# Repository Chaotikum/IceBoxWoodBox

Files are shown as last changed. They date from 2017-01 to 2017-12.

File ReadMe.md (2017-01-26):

# IceBoxWoodBox

Eine kleine Holzbox für die Icebox im nbsp;
die ersten Skizzen sind da, die Maße noch nicht endgültig alle geprüft, aber
ein erster Papier-Prototyp funktionierte ganz gut, von der Größe der
kleinen inneren Box abgesehen.
Im Nachtragen aller Maße (siehe erste Skizze, die bereits fertig ist), werden
die aufgefallenen Mängel mit behoben.

Außerdem müsste danach jemand lasern.

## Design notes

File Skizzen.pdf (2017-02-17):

# Die IceBoxWoodBox

An felgender erster Grafik sind alle Werte verzeichnet, die sich per Variable ändern lassen: Tiefe (oben) Höhe (vorne), Displayhöhe, (in dieser Grafik nicht enthalten: Displaybreite), Holzdicke, sowie Höhe und Tiefe der inneren Box.

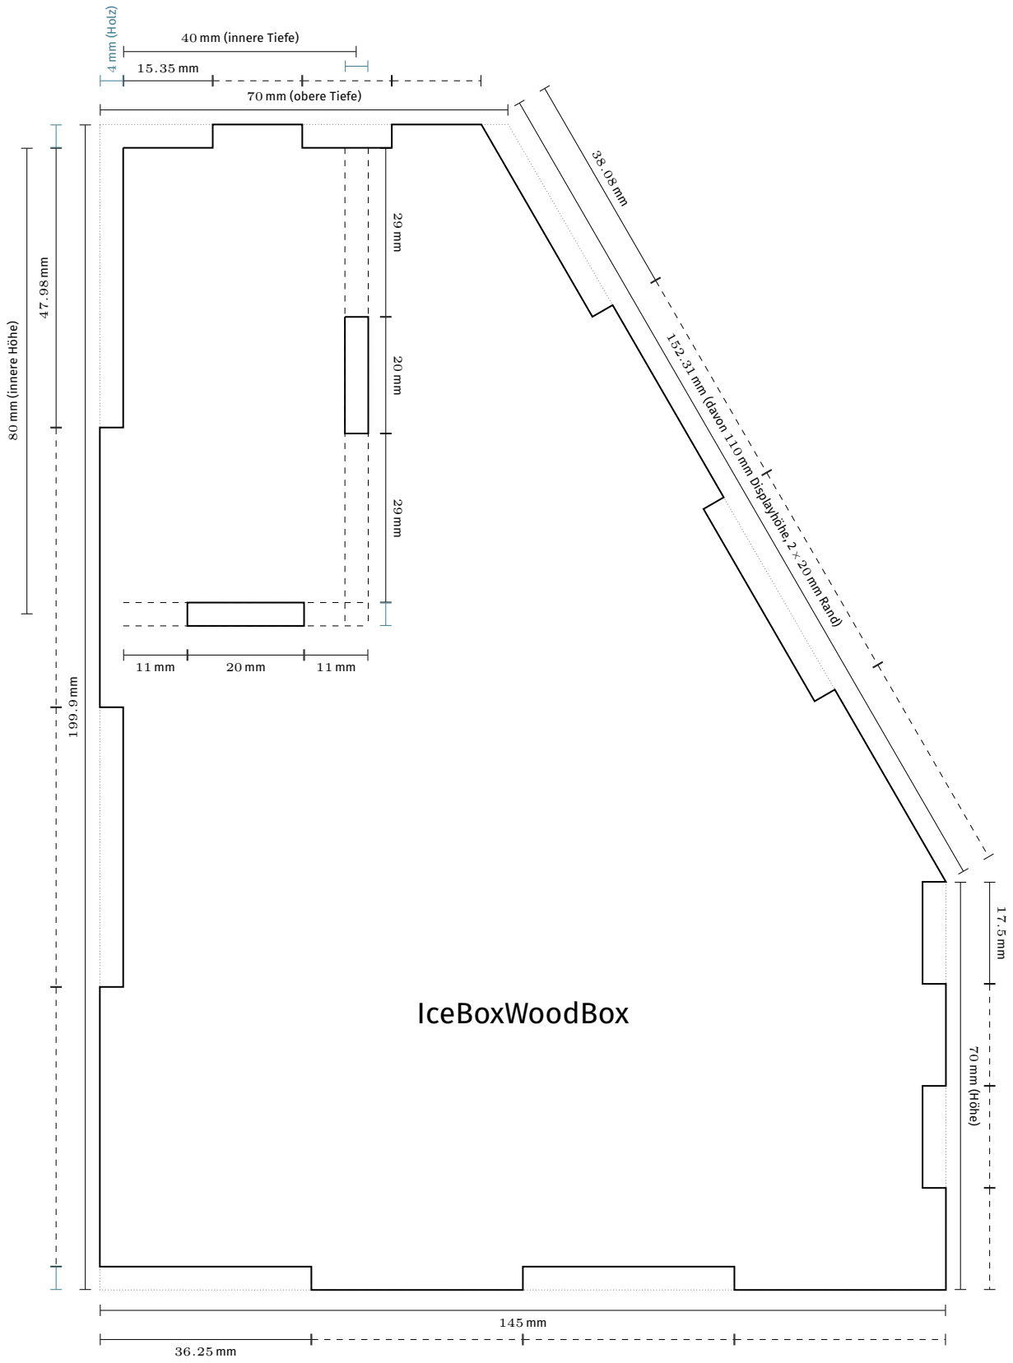
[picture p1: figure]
IceBoxWoodBox; 70 mm (obere Tiefe); mm (Holz); 40 mm (innere Tiefe); 152.31 mm (davon; 110 mm Displayhöhe, 2 × 20 mm Rand); 70 mm (Höhe); 80 mm (innere Höhe)

1 – (linke) Seitenansicht, die rechte Seite ist natürlich identisch, bzw. lediglich gespiegelt.

# Spenden- & Getränkekasse

Hinten
Vorne

69.38 mm

15.35 mm

40 mm (innere Tiefe)

7.5 mm (Geldschlitztiefe)

210 mm (davon 170 mm Display-Breite und 2×20 mm Display-Rand)

40.4 mm

40 mm (Geldschlitzt-Breite)

2 – Oberseite (links hinten, rechts vorne)

Oben

51.98 mm | 47.98 mm

80 mm (innere Höhe)

210 mm (davon 170 mm Display-Breite und 2×20 mm Display-Rand)

44.4 mm 40.4 mm 40.4 mm 40.4 mm 44.4 mm

42.5 mm 20 mm 85 mm 20 mm 42.5 mm

3 – Rückseite

Back

Front

210 mm (davon 170 mm Display-Breite und 2×20 mm Display-Rand)

44.4 mm 40.4 mm 40.4 mm 40.4 mm 44.4 mm

145 mm

36.25 mm | 35.85 mm
4 – Unterseite

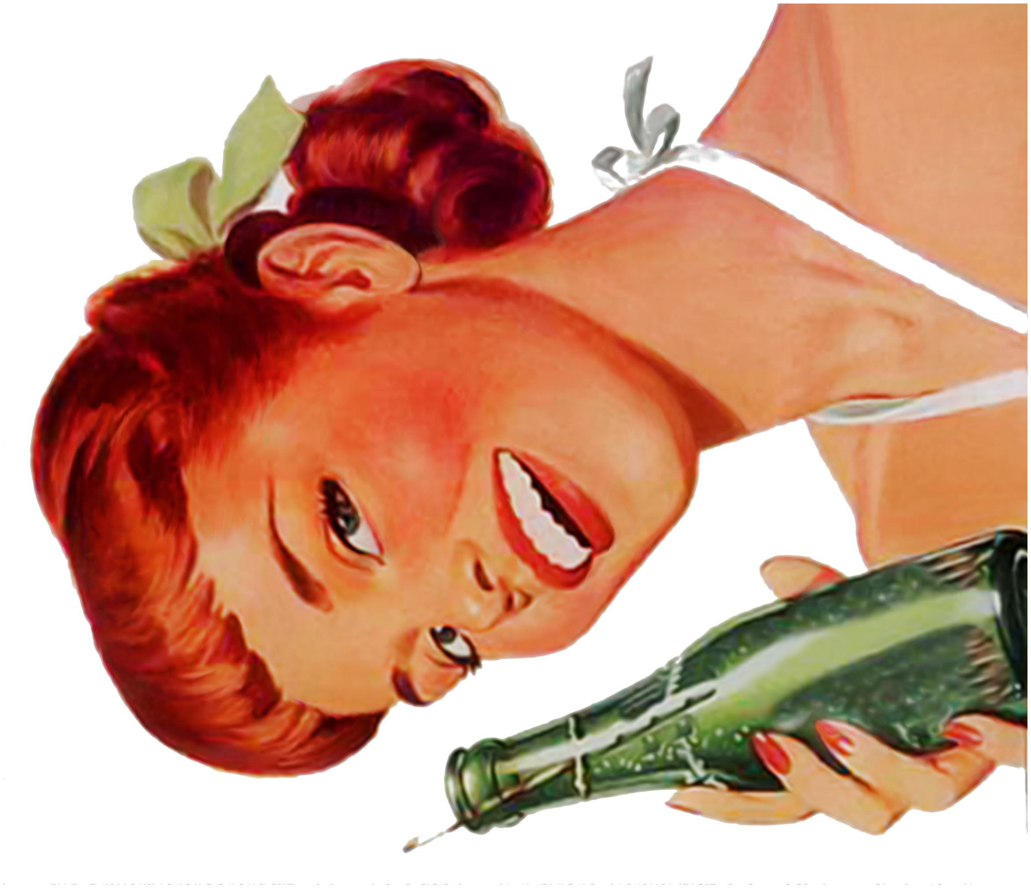
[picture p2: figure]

# icebox.nobreakspace.org

Klick dir ’ne Mate.

oben, ohne Finger, Kante zur Schräge

Unten

210 mm (davon 170 mm Display-Breite und 2×20 mm Display-Rand)

44.4 mm 40.4 mm 40.4 mm 40.4 mm 44.4 mm

70 mm (Höhe)

17.5 mm
5 – Frontblende unten

oben

vorne

210 mm (davon 170 mm Display-Breite und 2×20 mm Display-Rand)

44.4 mm 40.4 mm 40.4 mm 40.4 mm 44.4 mm

147.69 mm (vgl. Seitenansicht, gekürztes unteres Ende, damit die Schräge nicht übersteht)

38.08 mm | 33.46 mm
6 – Displayplatte

top

bottom
202 mm

38.5 mm 20 mm 85 mm 20 mm 38.5 mm

40.4 mm

80 mm (innere Höhe)

29 mm | 20 mm | 29 mm
7 – innere Box – Rückseite

back

front
202 mm

38.5 mm 20 mm 85 mm 20 mm 38.5 mm

40.4 mm

40 mm (innere Tiefe)

9 mm | 20 mm | 9 mm
8 – Boxbox-Unterseite

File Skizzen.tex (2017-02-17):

% !TEX TS-program = xelatex
% !TEX TS-options = --shell-escape

%
% A unified file to generate the sketches (PDF/Vectorgraphics) of the
%   Stackenblocken Pixel construction
%
% @kellertuer, 2017-01-01
\documentclass[a4paper,DIV=19]{scrartcl}
\usepackage[no-math]{fontspec}
\usepackage{xunicode,xltxtra}
\usepackage{tikz}
\usepackage{unicode-math,graphicx}
\usepackage[ngerman]{babel}
\usetikzlibrary{calc,external}
\tikzexternalize
\pagestyle{empty}
% Font
\defaultfontfeatures{Mapping=tex-text}
\setromanfont[Ligatures={Common}]{Fira Sans}
%
% Styles
\tikzset{base/.style={gray,densely dotted,thin}}
\tikzset{main/.style={thick}}
\tikzset{minor/.style={dashed}}
\tikzset{holes/.style={thick,fill=yellow!20}}
\tikzset{magnets/.style={thick,fill=cyan!20}}
\tikzset{measure/.style={thin,|-|}}
\tikzset{measureW/.style={thin,|-|,cyan!50!black}}
\tikzset{measure2/.style={thin,|-|,dashed}}
\tikzset{emph/.style={fill=cyan!10!white,cyan!60!white}}
\tikzset{neo/.style={fill=cyan!20!white,cyan!60!white}}
\tikzset{every node/.style={font=\tiny}}
%
% Details anzeigen oder nur Schnittlinien?
\newif\ifshowDetails
\showDetailstrue
%\showDetailsfalse
\ifshowDetails
  \tikzexternalize[prefix=SkizzeKompl-]
\else
  \tikzexternalize[prefix=Skizze-]
\fi
%
%
% Größenangaben
%
% if unsure leave them as they're because that's the production standard for now
\newcommand\DisplayWidth{17} %Displaybreite (brutto)
\newcommand\DisplayHeight{11} %DisplayHöhe
\newcommand\DisplayBorder{2} %(Holz-)Rand um das Displayplexi frontplare Thickness
\newcommand\Depth{7} %Tiefe hinter dem Display bzw unter dem Display
\newcommand\Height{7} %Höhe unter dem Display bzw unter dem Display
\newcommand\Boxboxdepth{4} % Tiefe der Gelbdbox
\newcommand\Boxboxheight{8} % Höhe der inneren Box
\newcommand\wood{0.4} % Das ist mein Holz

\newcommand\slotWidth{4}
\newcommand\slotHeight{0.75}

%Helper Values -- Bitte nicht bearbeiten
\newcommand\side{(\DisplayHeight+2*\DisplayBorder)}
\newcommand\sideHeight{\side*sin(60)}
\newcommand\sideWidth{\side*cos(60)}
\newcommand\topF{(\DisplayWidth+2*\DisplayBorder-2*\wood)}
\newcommand\measureOffSet{0.5}
\begin{document}
  \begin{center}
    \Huge Die IceBoxWoodBox
  \end{center}
  An felgender erster Grafik sind alle Werte verzeichnet, die sich per Variable ändern lassen:
  Tiefe (oben) Höhe (vorne), Displayhöhe, (in dieser Grafik nicht enthalten: Displaybreite),
  Holzdicke, sowie Höhe und Tiefe der inneren Box.
  \newpage\enlargethispage{3\baselineskip}
  \begin{center}
    \tikzsetnextfilename{Links}
    \tikzexternaldisable
    \begin{tikzpicture}
      % Elementgrenzen und andere Holzteile im Anschnitt
      \ifshowDetails
        \draw[base] (0,0) -- ++(\Depth,0)
            -- ++({\sideWidth},{-\sideHeight}) -- ++(0,-\Height) node (BottomRight) {}
            -- ++ (-\Depth,0) -- ++ ({-\sideWidth},0) node (Bottom Left) {} -- cycle;
      \fi
      % Umriss
      \draw[main] (\wood,-\wood) -- ++ ({((\Depth-\wood-\wood/sin(60))/4},0) -- ++ (0,\wood)
          -- ++ ({(\Depth-\wood-\wood/sin(60))/4},0) -- ++ (0,-\wood) 
          -- ++ ({(\Depth-\wood-\wood/sin(60))/4},0)
          -- ++ (0,\wood) -- ++ ({(\Depth-\wood-\wood/sin(60))/4},0) node (TR) {}
        -- ++ (300:{(\side+\wood/tan(60))/4}) -- ++ (30:\wood)
        -- ++ (300:{(\side+\wood/tan(60))/4}) -- ++ (210:\wood)
        -- ++ (300:{(\side+\wood/tan(60))/4}) -- ++ (30:\wood)
        -- ++ (300:{(\side+\wood/tan(60))/4}) node (BR) {} -- ++ (180:\wood) 
        -- ++ (270:{\Height/4}) -- ++ (0:\wood)
        -- ++ (270:{\Height/4}) -- ++ (180:\wood)
        -- ++ (270:{\Height/4}) -- ++ (0:\wood)
        -- ++ (270:{\Height/4})
        -- ++ (180:{(\Depth+\sideWidth)/4}) -- ++ (90:\wood)
        -- ++ (180:{(\Depth+\sideWidth)/4}) -- ++ (270:\wood)
        -- ++ (180:{(\Depth+\sideWidth)/4}) -- ++ (90:\wood)
        -- ++ (180:{(\Depth+\sideWidth)/4}) node[pos=1] (BL) {}
        -- ++ (90: { (\sideHeight+\Height-2*\wood)/4}) -- ++ (0:\wood)
        -- ++ (90: { (\sideHeight+\Height-2*\wood)/4}) -- ++ (180:\wood)
        -- ++ (90: { (\sideHeight+\Height-2*\wood)/4}) -- ++ (0:\wood)
        -- ++ (90: { (\sideHeight+\Height-2*\wood)/4});
    % Löcher für die Mittleren Wände
    \draw[main] (0,0) ++ (0:{\wood/2+\Boxboxdepth}) node (BTR) {}
    ++(270:{(\Boxboxheight+3*\wood/2)/2-1})
    -- ++(270:2) -- ++(0:\wood) -- ++(90:2) -- ++(180:\wood);
      \node[anchor = south,align=center] at ( $(BR) !.5! (BL) $)
        {\Large IceBoxWoodBox\\\vspace{2\baselineskip}};
      \draw[main] ({\wood+(\Boxboxdepth+\wood/2)/2-1},-\Boxboxheight-\wood/2)
        rectangle ({\wood+(\Boxboxdepth+\wood/2)/2+1},-\Boxboxheight-3*\wood/2);
      \ifshowDetails
        \draw[minor] (\Boxboxdepth+\wood/2,-\wood) -- (\Boxboxdepth+\wood/2,{-\wood-\Boxboxheight-\wood/2});
        \draw[minor] (\Boxboxdepth+3*\wood/2,-\wood) -- (\Boxboxdepth+3*\wood/2,{-\wood-\Boxboxheight-\wood/2});
        \draw[minor] (\wood,-\Boxboxheight-3*\wood/2) -- (\Boxboxdepth+3*\wood/2,-\Boxboxheight-3*\wood/2) node[pos=0] (BUR) {};
        \draw[minor] (\wood,-\Boxboxheight-\wood/2) -- (\Boxboxdepth+3*\wood/2,-\Boxboxheight-\wood/2);
        % Maße - oben
        \draw[measure] (0,0.5*\measureOffSet) -- ++(\Depth,0) node[midway,above]
          {\pgfmathparse{10*\Depth}\pgfmathprintnumber{\pgfmathresult}\,mm (obere Tiefe)};
        \draw[measure] (\wood,1.5*\measureOffSet) -- ++ ({(\Depth-\wood-\wood/sin(60))/4},0) node[midway, above]
          {\pgfmathparse{10*(\Depth-\wood-\wood/sin(60))/4}\pgfmathprintnumber{\pgfmathresult}\,mm};
        \draw[measure2] ({\wood+(\Depth-\wood-\wood/sin(60))/4},1.5*\measureOffSet) -- ++ ({(\Depth-\wood-\wood/sin(60))/4},0);
        \draw[measure2] ({\wood+2*(\Depth-\wood-\wood/sin(60))/4},1.5*\measureOffSet) -- ++ ({(\Depth-\wood-\wood/sin(60))/4},0);
        \draw[measure2] ({\wood+3*(\Depth-\wood-\wood/sin(60))/4},1.5*\measureOffSet) -- ++ ({(\Depth-\wood-\wood/sin(60))/4},0);
        \draw[measureW] (0,1.5*\measureOffSet) -- ++ (\wood,0) node[midway, right,rotate=90]
          {\pgfmathparse{10*\wood}\pgfmathprintnumber{\pgfmathresult}\,mm (Holz)};      
        \draw[measure] (\wood,2.5*\measureOffSet) -- ++ (\Boxboxdepth,0) node[midway, above]
          {\color{black}\pgfmathparse{10*\Boxboxdepth}\pgfmathprintnumber{\pgfmathresult}\,mm (innere Tiefe)};
        \draw[measureW] ({\Boxboxdepth+\wood/2},2*\measureOffSet) -- ++ (\wood,0);
        % rechts
        \draw[measure] (TR) ++ (30:1.5*\measureOffSet) -- ++ (300:{\side+\wood/tan(60)}) node[midway,above,rotate=-60]
          {\pgfmathparse{10*(\side+\wood/tan(60))}%
            \pgfmathprintnumber{\pgfmathresult}\,mm\ %
            (davon \pgfmathparse{10*\DisplayHeight}\pgfmathprintnumber{\pgfmathresult}\,mm Displayhöhe,\ %
            2\,$\times$\,\pgfmathparse{10*\DisplayBorder}\pgfmathprintnumber{\pgfmathresult}\,mm Rand)};
        \draw[measure] (TR) ++ (30:2.5*\measureOffSet) -- ++ (300:{(\side+\wood/tan(60))/4}) node[midway,above,rotate=-60]
          {\pgfmathparse{10*(\side+\wood/tan(60))/4}\pgfmathprintnumber{\pgfmathresult}\,mm};
        \draw[measure2] (TR) ++ (30:2.5*\measureOffSet) ++ (300:{(\side+\wood/tan(60))/4})
          -- ++ (300:{(\side+\wood/tan(60))/4});
        \draw[measure2] (TR) ++ (30:2.5*\measureOffSet) ++ (300:{2*(\side+\wood/tan(60))/4})
          -- ++ (300:{(\side+\wood/tan(60))/4});
        \draw[measure2] (TR) ++ (30:2.5*\measureOffSet) ++ (300:{3*(\side+\wood/tan(60))/4})
          -- ++ (300:{(\side+\wood/tan(60))/4});
        % box rechts
        \draw[measure] (BTR) ++ (0:{\wood/2+\measureOffSet}) ++(270:\wood)
          -- ++(270:{(\Boxboxheight-\wood/2)/2-1}) node[midway,above,rotate=-90]
          {\pgfmathparse{10*((\Boxboxheight-\wood/2)/2-1)}\pgfmathprintnumber{\pgfmathresult}\,mm}
          node[pos=1] (BTR1) {};
        \draw[measure] (BTR1.center) -- ++(270:2) node[midway,above,rotate=-90]
          {\pgfmathparse{20}\pgfmathprintnumber{\pgfmathresult}\,mm} node[pos=1] (BTR2) {};
        \draw[measure] (BTR2.center) -- ++(270:{(\Boxboxheight-\wood/2)/2-1}) node[midway,above,rotate=-90]
          {\pgfmathparse{10*((\Boxboxheight-\wood/2)/2-1)}\pgfmathprintnumber{\pgfmathresult}\,mm}
          node[pos=1] (BTR3) {};
        \draw[measureW] (BTR3.center) -- ++ (270:\wood);
        % box unten
        \draw[measure] (BUR.center) ++ (270:\measureOffSet) -- ++ (0:{(\Boxboxdepth+\wood/2)/2-1}) node[pos=1] (BUR1) {}
        node[midway, below] {\pgfmathparse{10*((\Boxboxdepth+\wood/2)/2-1)}\pgfmathprintnumber{\pgfmathresult}\,mm};
        \draw[measure] (BUR1.center) -- ++(0:2) node[midway,below]
          {\pgfmathparse{20}\pgfmathprintnumber{\pgfmathresult}\,mm} node[pos=1] (BUR2) {};
        \draw[measure] (BUR2.center) -- ++ (0:{(\Boxboxdepth+\wood/2)/2-1})
        node[midway, below] {\pgfmathparse{10*((\Boxboxdepth+\wood/2)/2-1)}\pgfmathprintnumber{\pgfmathresult}\,mm};
        % rechts
        \draw[measure] (BR.center) ++(0:.5*\measureOffSet) -- ++(270:\Height) node[midway,above,rotate=-90]
          {\pgfmathparse{10*\Height}\pgfmathprintnumber{\pgfmathresult}\,mm (Höhe)};
        \draw[measure] (BR.center) ++(0:1.5*\measureOffSet) -- ++(270:\Height/4) node[midway,above,rotate=-90]
          {\pgfmathparse{10*\Height/4}\pgfmathprintnumber{\pgfmathresult}\,mm};
        \draw[measure2] (BR.center) ++(0:1.5*\measureOffSet) ++(270:\Height/4) -- ++(270:\Height/4);
        \draw[measure2] (BR.center) ++(0:1.5*\measureOffSet) ++(270:2*\Height/4) -- ++(270:\Height/4);
        \draw[measure2] (BR.center) ++(0:1.5*\measureOffSet) ++(270:3*\Height/4) -- ++(270:\Height/4);
        % links
        \draw[measure] (0,0) ++(180:.5*\measureOffSet) -- ++(270:{\sideHeight+\Height}) node[midway,above,rotate=90]
        {\pgfmathparse{10*(\sideHeight+\Height)}\pgfmathprintnumber{\pgfmathresult}\,mm};
        \draw[measureW] (0,0) ++(180:1.5*\measureOffSet) -- ++(270:\wood);
        \draw[measure] (0,0) ++(180:1.5*\measureOffSet) ++(270:\wood)
          -- ++(270:{(\sideHeight+\Height-2*\wood)/4}) node[midway,above,rotate=90]
        {\pgfmathparse{10*(\sideHeight+\Height-2*\wood)/4}\pgfmathprintnumber{\pgfmathresult}\,mm};
        \draw[measure2] (0,0) ++(180:1.5*\measureOffSet) ++(270:{\wood+(\sideHeight+\Height-2*\wood)/4})
          -- ++(270:{(\sideHeight+\Height-2*\wood)/4});
        \draw[measure2] (0,0) ++(180:1.5*\measureOffSet) ++(270:{\wood+2*(\sideHeight+\Height-2*\wood)/4})
          -- ++(270:{(\sideHeight+\Height-2*\wood)/4});
        \draw[measure2] (0,0) ++(180:1.5*\measureOffSet) ++(270:{\wood+3*(\sideHeight+\Height-2*\wood)/4})
          -- ++(270:{(\sideHeight+\Height-2*\wood)/4});
        \draw[measureW] (0,0) ++(180:1.5*\measureOffSet) ++(270:{\wood+4*(\sideHeight+\Height-2*\wood)/4})
          -- ++(270:\wood);
        \draw[measure] (0,0) ++(180:2.5*\measureOffSet) ++(270:\wood) -- ++(270:\Boxboxheight) node[midway,above,rotate=90]
          {\pgfmathparse{10*(\Boxboxheight)}\pgfmathprintnumber{\pgfmathresult}\,mm (innere Höhe)};
        % unten
        \draw[measure] (BL.center) ++ (270:1.5*\measureOffSet) -- ++ (0:{(\Depth+\sideWidth)}) node[midway, below]
          {\pgfmathparse{10*(\Depth+\sideWidth)}\pgfmathprintnumber{\pgfmathresult}\,mm};
        \draw[measure] (BL.center) ++ (270:2.5*\measureOffSet) -- ++ (0:{(\Depth+\sideWidth)/4}) node[midway, below]
          {\pgfmathparse{10*(\Depth+\sideWidth)/4}\pgfmathprintnumber{\pgfmathresult}\,mm};
        \draw[measure2] (BL.center) ++ (270:2.5*\measureOffSet) ++ (0:{(\Depth+\sideWidth)/4}) -- ++ (0:{(\Depth+\sideWidth)/4});
        \draw[measure2] (BL.center) ++ (270:2.5*\measureOffSet) ++ (0:{2*(\Depth+\sideWidth)/4}) -- ++ (0:{(\Depth+\sideWidth)/4});
        \draw[measure2] (BL.center) ++ (270:2.5*\measureOffSet) ++ (0:{3*(\Depth+\sideWidth)/4}) -- ++ (0:{(\Depth+\sideWidth)/4});
      \fi
    \end{tikzpicture}
      \\
      1 – (linke) Seitenansicht, die rechte Seite ist natürlich identisch, bzw. lediglich gespiegelt.
  \end{center}
  \newpage\enlargethispage{4\baselineskip}
  \begin{center}
    \tikzexternaldisable
    \begin{tikzpicture}[rotate=90]
      \ifshowDetails
        \draw[base] (0,0) rectangle ({\DisplayWidth+2*\DisplayBorder},-\Depth);
      \fi
      \draw[main] (0,-\wood) 
            -- ++(270:{((\Depth-\wood-\wood/sin(60))/4}) -- ++(0:\wood)
            -- ++(270:{((\Depth-\wood-\wood/sin(60))/4}) -- ++(180:\wood)
            -- ++(270:{((\Depth-\wood-\wood/sin(60))/4}) -- ++(0:\wood)
            -- ++(270:{((\Depth-\wood-\wood/sin(60))/4})
            -- ++ (0:{\topF/5}) -- ++(270:\wood)
            -- ++ (0:{\topF/5}) -- ++(90:\wood)
            -- ++ (0:{\topF/5}) -- ++(270:\wood)
            -- ++ (0:{\topF/5}) -- ++(90:\wood)
            -- ++ (0:{\topF/5})
            -- ++(90:{((\Depth-\wood-\wood/sin(60))/4}) -- ++(0:\wood)
            -- ++(90:{((\Depth-\wood-\wood/sin(60))/4}) -- ++(180:\wood)
            -- ++(90:{((\Depth-\wood-\wood/sin(60))/4}) -- ++(0:\wood)
            -- ++(90:{((\Depth-\wood-\wood/sin(60))/4})
            -- ++ (180:{\wood+\topF/5}) -- ++(90:\wood)
            -- ++ (180:{\topF/5}) -- ++(270:\wood)
            -- ++ (180:{\topF/5}) -- ++(90:\wood)
            -- ++ (180:{\topF/5}) -- ++(270:\wood)
            -- ++ (180:{\wood+\topF/5});
        \draw[main]
        % slot
        ({(\DisplayWidth+2*\DisplayBorder)/2-\slotWidth/2},{-\wood/2-\Boxboxdepth/2+\slotHeight/2})
        rectangle
        ({(\DisplayWidth+2*\DisplayBorder)/2+\slotWidth/2},{-\wood/2-\Boxboxdepth/2-\slotHeight/2});
        \draw[main]
        % holes for boxbox back
        ({(\DisplayWidth+2*\DisplayBorder)/4-1},-\Boxboxdepth-3*\wood/2)
        rectangle
        ({(\DisplayWidth+2*\DisplayBorder)/4+1},-\Boxboxdepth-\wood/2);
        \draw[main]
        % holes for boxbox back
        ({3*(\DisplayWidth+2*\DisplayBorder)/4-1},-\Boxboxdepth-3*\wood/2)
        rectangle
        ({3*(\DisplayWidth+2*\DisplayBorder)/4+1},-\Boxboxdepth-\wood/2);
        \node[font=\Huge,rotate=90] at ({(\DisplayWidth+2*\DisplayBorder)/2},{-\Depth/2}) {Spenden- \& Getränkekasse};
      \ifshowDetails
        \draw[minor] (\wood,-\Boxboxdepth-\wood/2) -- ({\DisplayWidth+2*\DisplayBorder-\wood},-\Boxboxdepth-\wood/2);
        \draw[minor] (\wood,-\Boxboxdepth-3*\wood/2) -- ({\DisplayWidth+2*\DisplayBorder-\wood},-\Boxboxdepth-3*\wood/2);
        \node[xshift=-.5\baselineskip,rotate=90] (A) at ({(\DisplayWidth+2*\DisplayBorder)/2},0) {Hinten};
        \node[xshift=.5\baselineskip,rotate=90] (B) at ({(\DisplayWidth+2*\DisplayBorder)/2},-\Depth) {Vorne};
        % unten
        \draw[measure] ({-.5*\measureOffSet},0) -- ++ (270:{\wood+\Depth-\wood-\wood/sin(60)}) node[midway,below]
          {\pgfmathparse{10*(\wood+\Depth-\wood/sin(60))}\pgfmathprintnumber{\pgfmathresult}\,mm};
        \draw[measureW] ({-1.5*\measureOffSet},0) -- ++ (270:{\wood});
        \draw[measure] ({-1.5*\measureOffSet},0) ++ (270:{\wood}) -- ++(270:{ (\Depth-\wood-\wood/sin(60))/4}) node [midway,below]
          {\pgfmathparse{10*(((\Depth-\wood-\wood/sin(60))/4}\pgfmathprintnumber{\pgfmathresult}\,mm};
        \draw[measure2] ({-1.5*\measureOffSet},0) ++ (270:{\wood+(\Depth-\wood-\wood/sin(60))/4})
          -- ++(270:{ (\Depth-\wood-\wood/sin(60))/4});
        \draw[measure2] ({-1.5*\measureOffSet},0) ++ (270:{\wood+2*(\Depth-\wood-\wood/sin(60))/4})
          -- ++(270:{ (\Depth-\wood-\wood/sin(60))/4});
        \draw[measure2] ({-1.5*\measureOffSet},0) ++ (270:{\wood+3*(\Depth-\wood-\wood/sin(60))/4})
          -- ++(270:{ (\Depth-\wood-\wood/sin(60))/4});
        \draw[measureW] ({-1.5*\measureOffSet},0) ++ (270:{\wood+4*(\Depth-\wood-\wood/sin(60))/4})
          -- ++(270:{\wood});
        \draw[measureW] ({-2*\measureOffSet},0) ++ (270:{\wood/2+\Boxboxdepth}) -- ++(270:\wood);
        \draw[measure] ({-2.5*\measureOffSet},0) ++ (270:{\wood}) 
        -- ++ (270:{\Boxboxdepth}) node[midway,below]
          {\pgfmathparse{10*(\Boxboxdepth)}\pgfmathprintnumber{\pgfmathresult}\,mm (innere Tiefe)};
        \draw[measure] ({-3.5*\measureOffSet},0) ++ (270:{(\wood/2+\Boxboxdepth/2-\slotHeight/2)}) 
        -- ++ (270:{\slotHeight}) node[midway,below]
          {\pgfmathparse{10*(\slotHeight)}\pgfmathprintnumber{\pgfmathresult}\,mm (Geldschlitztiefe)};
        % links
        \draw[measure] (0,\measureOffSet) -- ++ (0:{\topF+2*\wood}) node[midway,below,rotate=-90]
    {\pgfmathparse{10*(\topF+2*\wood)}\pgfmathprintnumber{\pgfmathresult}\,mm\ %
      (davon \pgfmathparse{10*\DisplayWidth}\pgfmathprintnumber{\pgfmathresult}\,mm\ Display-Breite
      und 2\(\times\)\pgfmathparse{10*\DisplayBorder}\pgfmathprintnumber{\pgfmathresult}\,mm\ Display-Rand)};
    \draw[measureW] (0,2*\measureOffSet) -- ++ (0:{\wood});
    \draw[measure] (0,2*\measureOffSet) ++ (0:\wood) -- ++(0:{\topF/5}) node[midway,below,rotate=-90]
      {\pgfmathparse{10*(\topF/5}\pgfmathprintnumber{\pgfmathresult}\,mm};
    \draw[measure2] (0,2*\measureOffSet) ++ (0:{\wood+\topF/5}) -- ++(0:{\topF/5});
    \draw[measure2] (0,2*\measureOffSet) ++ (0:{\wood+2*\topF/5}) -- ++(0:{\topF/5});
    \draw[measure2] (0,2*\measureOffSet) ++ (0:{\wood+3*\topF/5}) -- ++(0:{\topF/5});
    \draw[measure2] (0,2*\measureOffSet) ++ (0:{\wood+4*\topF/5}) -- ++(0:{\topF/5});
    \draw[measureW] (0,2*\measureOffSet) ++ (0:{\wood+5*\topF/5}) -- ++(0:{\wood});
    \draw[measure] (0,3*\measureOffSet) ++ (0:{\wood+\topF/2-\slotWidth/2}) -- ++(0:{\slotWidth}) node[midway,below,,rotate=-90]
      {\pgfmathparse{10*(\slotWidth}\pgfmathprintnumber{\pgfmathresult}\,mm (Geldschlitzt-Breite)};
      \fi
    \end{tikzpicture}
    \\
    2 – Oberseite (links hinten, rechts vorne)
  \end{center}
  \newpage
  \begin{center}  
    \tikzexternaldisable
    ~\hspace*{-1.25cm}\begin{tikzpicture}[rotate=90]
      \ifshowDetails
      \draw[base] (0,0) rectangle ({\DisplayWidth+2*\DisplayBorder},{-\sideHeight-\Height});
      \fi
      \draw[main] (0,0)%
      % top
      -- ++ (0:{\wood+\topF/5}) -- ++(270:\wood)
      -- ++ (0:{\topF/5}) -- ++(90:\wood)
      -- ++ (0:{\topF/5}) -- ++(270:\wood)
      -- ++ (0:{\topF/5}) -- ++(90:\wood)
      -- ++ (0:{\wood+\topF/5})
      % left
      -- ++ (270: { \wood+(\sideHeight+\Height-2*\wood)/4}) -- ++ (180:\wood)
      -- ++ (270: { (\sideHeight+\Height-2*\wood)/4}) -- ++ (0:\wood)
      -- ++ (270: { (\sideHeight+\Height-2*\wood)/4}) -- ++ (180:\wood)
      -- ++ (270: { (\sideHeight+\Height-2*\wood)/4})
      %bottom
      -- ++ (180:{\topF/5}) -- ++(270:\wood)
      -- ++ (180:{\topF/5}) -- ++(90:\wood)
      -- ++ (180:{\topF/5}) -- ++(270:\wood)
      -- ++ (180:{\topF/5}) -- ++(90:\wood)
      -- ++ (180:{\topF/5})
      %right
      -- ++ (90: { (\sideHeight+\Height-2*\wood)/4}) -- ++ (180:\wood)
      -- ++ (90: { (\sideHeight+\Height-2*\wood)/4}) -- ++ (0:\wood)
      -- ++ (90: { (\sideHeight+\Height-2*\wood)/4}) -- ++ (180:\wood)
      -- ++ (90: { \wood+(\sideHeight+\Height-2*\wood)/4})
      ;
      \draw[main, rounded corners=15] (0,0) ++ (270:{\Boxboxheight+\wood/2}) ++ (0:\DisplayBorder)
      -- ++(90:{\Boxboxheight-\DisplayBorder}) -- ++(0:\DisplayWidth) -- ++ (270:{\Boxboxheight-\DisplayBorder});
      \draw[main,] ({(\DisplayWidth/2+\DisplayBorder)},{(-\DisplayBorder-1.8)}) circle (10mm); 
      \draw[main] ({(\DisplayWidth+2*\DisplayBorder)/4-1},-\Boxboxheight-3*\wood/2)
        rectangle ({(\DisplayWidth+2*\DisplayBorder)/4+1},-\Boxboxheight-\wood/2);
      \draw[main] ({3*(\DisplayWidth+2*\DisplayBorder)/4-1},-\Boxboxheight-3*\wood/2)
        rectangle ({3*(\DisplayWidth+2*\DisplayBorder)/4+1},-\Boxboxheight-\wood/2);
      \ifshowDetails
        \node[xshift=-.5\baselineskip,rotate=90] (A) at ({(\DisplayWidth+2*\DisplayBorder)/2},0) {Oben};
        \node[xshift=.5\baselineskip,rotate=90] (B) at ({(\DisplayWidth+2*\DisplayBorder)/2},{-\sideHeight-\Depth}) {Unten};
        \draw[minor] (\wood,-\Boxboxheight-3*\wood/2) -- (\DisplayWidth+2*\DisplayBorder-\wood,-\Boxboxheight-3*\wood/2);
        \draw[minor] (\wood,-\Boxboxheight-\wood/2) -- (\DisplayWidth+2*\DisplayBorder-\wood,-\Boxboxheight-\wood/2);
        % unten
    \draw[measure] (-0.5*\measureOffSet,0) -- ++ (270: {\wood+(\sideHeight+\Height-2*\wood)/4}) node[midway,below]
      {\pgfmathparse{10*(\wood+(\sideHeight+\Height-2*\wood)/4}\pgfmathprintnumber{\pgfmathresult}\,mm};
    \draw[measure] (-0.5*\measureOffSet,0) ++ (270: {\wood+(\sideHeight+\Height-2*\wood)/4})
    -- ++ (270:{(\sideHeight+\Height-2*\wood)/4}) node[midway, below]
      {\pgfmathparse{10*((\sideHeight+\Height-2*\wood)/4}\pgfmathprintnumber{\pgfmathresult}\,mm};
    \draw[measure2] (-0.5*\measureOffSet,0) ++ (270: {\wood+2*(\sideHeight+\Height-2*\wood)/4})
    -- ++ (270:{(\sideHeight+\Height-2*\wood)/4});
    \draw[measure2] (-0.5*\measureOffSet,0) ++ (270: {\wood+3*(\sideHeight+\Height-2*\wood)/4})
    -- ++ (270:{(\sideHeight+\Height-2*\wood)/4});
    \draw[measureW] (-1.5*\measureOffSet,0) -- ++ (270:\wood);
    \draw[measure] (-1.5*\measureOffSet,-\wood) -- ++ (270: {\Boxboxheight}) node[midway,below]
      {\pgfmathparse{10*(\Boxboxheight)}\pgfmathprintnumber{\pgfmathresult}\,mm (innere Höhe)};
    \draw[measureW] (-2*\measureOffSet,{-\wood/2-\Boxboxheight}) -- ++ (270:\wood);
        % links
        \draw[measure] (0,\measureOffSet) -- ++ (0:{\topF+2*\wood}) node[midway,below,rotate=-90]
    {\pgfmathparse{10*(\topF+2*\wood)}\pgfmathprintnumber{\pgfmathresult}\,mm\ %
      (davon \pgfmathparse{10*\DisplayWidth}\pgfmathprintnumber{\pgfmathresult}\,mm\ Display-Breite
      und 2\(\times\)\pgfmathparse{10*\DisplayBorder}\pgfmathprintnumber{\pgfmathresult}\,mm\ Display-Rand)};
    \draw[measure] (0,2*\measureOffSet) -- ++(0:{\wood+\topF/5}) node[midway,below,rotate=-90]
      {\pgfmathparse{10*(\wood+\topF/5)}\pgfmathprintnumber{\pgfmathresult}\,mm};
    \draw[measure] (0,2*\measureOffSet) ++ (0:{\wood+\topF/5}) -- ++(0:{\topF/5}) node[midway,below,rotate=-90]
      {\pgfmathparse{10*(\topF/5)}\pgfmathprintnumber{\pgfmathresult}\,mm};
    \draw[measure2] (0,2*\measureOffSet) ++ (0:{\wood+2*\topF/5}) -- ++(0:{\topF/5}) node[midway,below,rotate=-90]
      {\pgfmathparse{10*(\topF/5)}\pgfmathprintnumber{\pgfmathresult}\,mm};
    \draw[measure2] (0,2*\measureOffSet) ++ (0:{\wood+3*\topF/5}) -- ++(0:{\topF/5}) node[midway,below,rotate=-90]
      {\pgfmathparse{10*(\topF/5)}\pgfmathprintnumber{\pgfmathresult}\,mm};
    \draw[measure2] (0,2*\measureOffSet) ++ (0:{\wood+4*\topF/5}) -- ++(0:{\topF/5+\wood})  node[midway,below,rotate=-90]
      {\pgfmathparse{10*(\wood+\topF/5)}\pgfmathprintnumber{\pgfmathresult}\,mm};
    \draw[measure] (0,3*\measureOffSet) -- ++ (0:{(\DisplayWidth+2*\DisplayBorder)/4-1}) node[midway,below,rotate=-90]
      {\pgfmathparse{10*((\DisplayWidth+2*\DisplayBorder)/4-1)}\pgfmathprintnumber{\pgfmathresult}\,mm};
    \draw[measure] (0,3*\measureOffSet) ++ (0:{(\DisplayWidth+2*\DisplayBorder)/4-1}) -- ++(0:2) node[midway,below,rotate=-90]
      {\pgfmathparse{20}\pgfmathprintnumber{\pgfmathresult}\,mm};
    \draw[measure] (0,3*\measureOffSet) ++ (0:{(\DisplayWidth+2*\DisplayBorder)/4+1}) -- ++(0:{(\DisplayWidth+2*\DisplayBorder)/2-2}) node[midway,below,rotate=-90]
      {\pgfmathparse{10*( (\DisplayWidth+2*\DisplayBorder)/2-2)}\pgfmathprintnumber{\pgfmathresult}\,mm};
    \draw[measure] (0,3*\measureOffSet) ++ (0:{(\DisplayWidth+2*\DisplayBorder)/4+1+(\DisplayWidth+2*\DisplayBorder)/2-2}) -- ++(0:2) node[midway,below,rotate=-90]
      {\pgfmathparse{20}\pgfmathprintnumber{\pgfmathresult}\,mm};
    \draw[measure] (0,3*\measureOffSet) ++ (0:{3*(\DisplayWidth+2*\DisplayBorder)/4+1}) -- ++(0:{(\DisplayWidth+2*\DisplayBorder)/4-1}) node[midway,below,rotate=-90]
      {\pgfmathparse{10*((\DisplayWidth+2*\DisplayBorder)/4-1)}\pgfmathprintnumber{\pgfmathresult}\,mm};
      \fi
    \end{tikzpicture}
    \\
    3 – Rückseite
  \end{center}
  \newpage
  \begin{center}\enlargethispage{8\baselineskip}
    \tikzexternaldisable
    \begin{tikzpicture}[rotate=90]
      \ifshowDetails
        \draw[base] (0,0) rectangle ({\DisplayWidth+2*\DisplayBorder},{-\sideWidth-\Depth});
      \fi
      \draw[main] (0,0)
      -- ++ (0:{\wood+\topF/5}) -- ++(270:\wood)
      -- ++ (0:{\topF/5}) -- ++(90:\wood)
      -- ++ (0:{\topF/5}) -- ++(270:\wood)
      -- ++ (0:{\topF/5}) -- ++(90:\wood)
      -- ++ (0:{\wood+\topF/5})
      -- ++ (270:{(\Depth+\sideWidth)/4}) -- ++ (180:\wood)
      -- ++ (270:{(\Depth+\sideWidth)/4}) -- ++ (0:\wood)
      -- ++ (270:{(\Depth+\sideWidth)/4}) -- ++ (180:\wood)
      -- ++ (270:{(\Depth+\sideWidth)/4-\wood})
      % front
      -- ++ (180:{\topF/5}) -- ++(270:\wood)
      -- ++ (180:{\topF/5}) -- ++(90:\wood)
      -- ++ (180:{\topF/5}) -- ++(270:\wood)
      -- ++ (180:{\topF/5}) -- ++(90:\wood)
      -- ++ (180:{\topF/5})
      -- ++ (90:{(\Depth+\sideWidth)/4-\wood}) -- ++ (180:\wood)
      -- ++ (90:{(\Depth+\sideWidth)/4}) -- ++ (0:\wood)
      -- ++ (90:{(\Depth+\sideWidth)/4}) -- ++ (180:\wood)
      -- ++ (90:{(\Depth+\sideWidth)/4})
      ;
      \ifshowDetails
        \node[xshift=-.5\baselineskip,rotate=90] (A) at ({(\DisplayWidth+2*\DisplayBorder)/2},0) {Back};
        \node[xshift=.5\baselineskip,rotate=90] (B) at ({(\DisplayWidth+2*\DisplayBorder)/2},{-\sideWidth-\Depth}) {Front};
        % links
        \draw[measure] (0,\measureOffSet) -- ++ (0:{\topF+2*\wood}) node[midway,below,rotate=-90]
    {\pgfmathparse{10*(\topF+2*\wood)}\pgfmathprintnumber{\pgfmathresult}\,mm\ %
      (davon \pgfmathparse{10*\DisplayWidth}\pgfmathprintnumber{\pgfmathresult}\,mm\ Display-Breite
      und 2\(\times\)\pgfmathparse{10*\DisplayBorder}\pgfmathprintnumber{\pgfmathresult}\,mm\ Display-Rand)};
    \draw[measure] (0,2*\measureOffSet) -- ++(0:{\wood+\topF/5}) node[midway,below,rotate=-90]
      {\pgfmathparse{10*(\wood+\topF/5)}\pgfmathprintnumber{\pgfmathresult}\,mm};
    \draw[measure] (0,2*\measureOffSet) ++ (0:{\wood+\topF/5}) -- ++(0:{\topF/5}) node[midway,below,rotate=-90]
      {\pgfmathparse{10*(\topF/5)}\pgfmathprintnumber{\pgfmathresult}\,mm};
    \draw[measure2] (0,2*\measureOffSet) ++ (0:{\wood+2*\topF/5}) -- ++(0:{\topF/5}) node[midway,below,rotate=-90]
      {\pgfmathparse{10*(\topF/5)}\pgfmathprintnumber{\pgfmathresult}\,mm};
    \draw[measure2] (0,2*\measureOffSet) ++ (0:{\wood+3*\topF/5}) -- ++(0:{\topF/5}) node[midway,below,rotate=-90]
      {\pgfmathparse{10*(\topF/5)}\pgfmathprintnumber{\pgfmathresult}\,mm};
    \draw[measure2] (0,2*\measureOffSet) ++ (0:{\wood+4*\topF/5}) -- ++(0:{\topF/5+\wood})  node[midway,below,rotate=-90]
      {\pgfmathparse{10*(\wood+\topF/5)}\pgfmathprintnumber{\pgfmathresult}\,mm};
      % unten
      \draw[measure] (0,0) ++ (180:.5*\measureOffSet) -- ++ (270:{(\Depth+\sideWidth)}) node[midway, below]
        {\pgfmathparse{10*(\Depth+\sideWidth)}\pgfmathprintnumber{\pgfmathresult}\,mm};
      \draw[measure] (0,0) ++ (180:1.5*\measureOffSet) -- ++ (270:{(\Depth+\sideWidth)/4}) node[midway, below]
        {\pgfmathparse{10*(\Depth+\sideWidth)/4}\pgfmathprintnumber{\pgfmathresult}\,mm};
      \draw[measure2] (0,0) ++ (180:1.5*\measureOffSet) ++ (270:{(\Depth+\sideWidth)/4}) -- ++ (270:{(\Depth+\sideWidth)/4});
      \draw[measure2] (0,0) ++ (180:1.5*\measureOffSet) ++ (270:{2*(\Depth+\sideWidth)/4}) -- ++ (270:{(\Depth+\sideWidth)/4});
      \draw[measure] (0,0) ++ (180:1.5*\measureOffSet) ++ (270:{3*(\Depth+\sideWidth)/4}) -- ++ (270:{(\Depth+\sideWidth)/4-\wood}) node[midway, below]
        {\pgfmathparse{10*(\Depth+\sideWidth)/4-\wood}\pgfmathprintnumber{\pgfmathresult}\,mm};
      \draw[measureW] (0,0) ++ (180:1.5*\measureOffSet) ++ (270:{(\Depth+\sideWidth)-\wood}) -- ++ (270:{\wood});
      
      \fi
    \end{tikzpicture}
    \\
    4 – Unterseite
  \end{center}
  \newpage
  \begin{center}
    \tikzexternaldisable
    \begin{tikzpicture}[rotate=90]
      \ifshowDetails
        \draw[base] (0,0) rectangle ({\DisplayWidth+2*\DisplayBorder},{-\Height});
      \fi
      \draw[main] (0,0)
      -- ++ (270:{\Height/4}) -- ++ (0:\wood)
      -- ++ (270:{\Height/4}) -- ++ (180:\wood)
      -- ++ (270:{\Height/4}) -- ++ (0:\wood)
      -- ++ (270:{\Height/4})
      -- ++ (0:{\topF/5}) -- ++(90:\wood)
      -- ++ (0:{\topF/5}) -- ++(270:\wood)
      -- ++ (0:{\topF/5}) -- ++(90:\wood)
      -- ++ (0:{\topF/5}) -- ++(270:\wood)
      -- ++ (0:{\topF/5})
      -- ++ (90:{\Height/4}) -- ++ (0:\wood)
      -- ++ (90:{\Height/4}) -- ++ (180:\wood)
      -- ++ (90:{\Height/4}) -- ++ (00:\wood)
      -- ++ (90:{\Height/4})
      -- %
      % -- ++ (180:{\wood+\topF/5}) -- ++(270:\wood)
      % -- ++ (180:{\topF/5}) -- ++(90:\wood)
      % -- ++ (180:{\topF/5}) -- ++(270:\wood)
      % -- ++ (180:{\topF/5}) -- ++(90:\wood)
      % -- ++ (180:{\wood+\topF/5})
      cycle;
      \node[font=\fontsize{40}{50}\selectfont,rotate=90] (T) at ({\topF/2-1.5},{-\Height/2-\wood}) {icebox.nobreakspace.org};
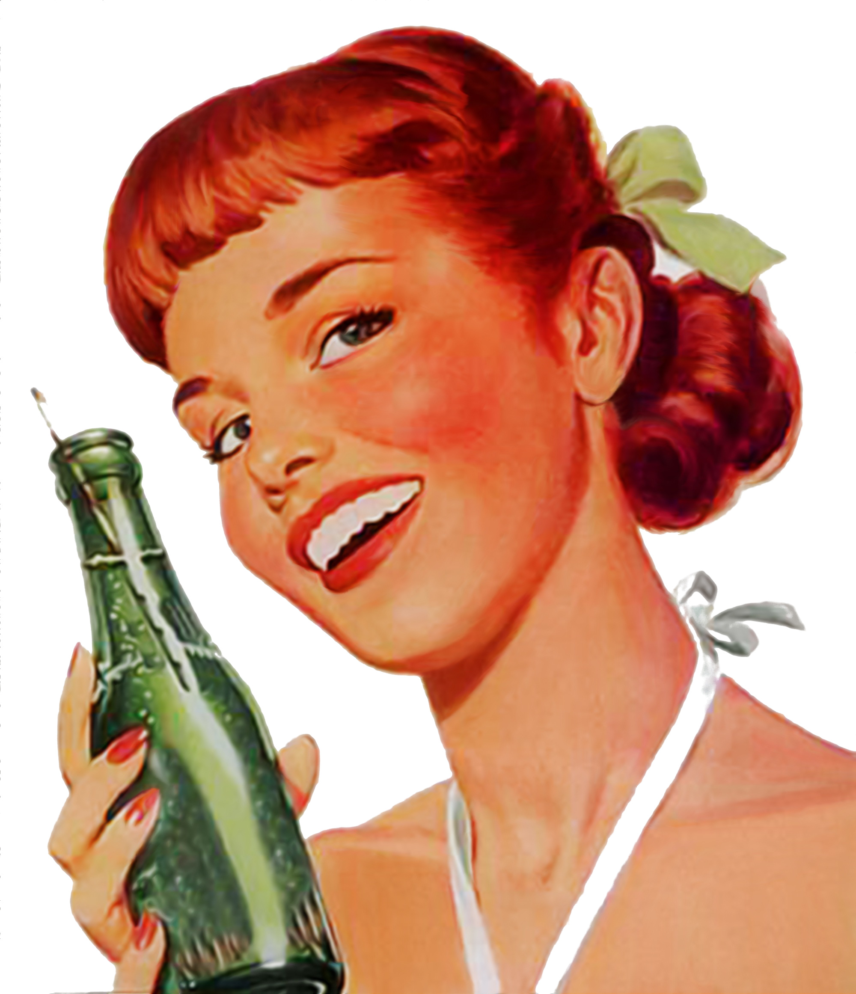
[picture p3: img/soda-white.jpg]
      \node[rotate=90,anchor=east] (T) at ({\topF+\wood/2},{-\Height/2}) {};
      \node[font=\Huge, rotate=90] (T2) at ({\topF/2},{-2*\wood}) {Klick dir 'ne Mate.};
      \ifshowDetails
        \node[xshift=-.5\baselineskip,rotate=90] (A) at ({(\DisplayWidth+2*\DisplayBorder)/2},0) {oben, ohne Finger, Kante zur Schräge};
        \node[xshift=.5\baselineskip,rotate=90] (B) at ({(\DisplayWidth+2*\DisplayBorder)/2},{-\Height}) {Unten};
        % links
        \draw[measure] (0,\measureOffSet) -- ++ (0:{\topF+2*\wood}) node[midway,below,rotate=-90]
    {\pgfmathparse{10*(\topF+2*\wood)}\pgfmathprintnumber{\pgfmathresult}\,mm\ %
      (davon \pgfmathparse{10*\DisplayWidth}\pgfmathprintnumber{\pgfmathresult}\,mm\ Display-Breite
      und 2\(\times\)\pgfmathparse{10*\DisplayBorder}\pgfmathprintnumber{\pgfmathresult}\,mm\ Display-Rand)};
    \draw[measure] (0,2*\measureOffSet) -- ++(0:{\wood+\topF/5}) node[midway,below,rotate=-90]
      {\pgfmathparse{10*(\wood+\topF/5)}\pgfmathprintnumber{\pgfmathresult}\,mm};
    \draw[measure] (0,2*\measureOffSet) ++ (0:{\wood+\topF/5}) -- ++(0:{\topF/5}) node[midway,below,rotate=-90]
      {\pgfmathparse{10*(\topF/5)}\pgfmathprintnumber{\pgfmathresult}\,mm};
    \draw[measure2] (0,2*\measureOffSet) ++ (0:{\wood+2*\topF/5}) -- ++(0:{\topF/5}) node[midway,below,rotate=-90]
      {\pgfmathparse{10*(\topF/5)}\pgfmathprintnumber{\pgfmathresult}\,mm};
    \draw[measure2] (0,2*\measureOffSet) ++ (0:{\wood+3*\topF/5}) -- ++(0:{\topF/5}) node[midway,below,rotate=-90]
      {\pgfmathparse{10*(\topF/5)}\pgfmathprintnumber{\pgfmathresult}\,mm};
    \draw[measure2] (0,2*\measureOffSet) ++ (0:{\wood+4*\topF/5}) -- ++(0:{\topF/5+\wood})  node[midway,below,rotate=-90]
      {\pgfmathparse{10*(\wood+\topF/5)}\pgfmathprintnumber{\pgfmathresult}\,mm};
        % rechts
        \draw[measure] (0,0) ++(0:-.5*\measureOffSet) -- ++(270:\Height) node[midway,below]
          {\pgfmathparse{10*\Height}\pgfmathprintnumber{\pgfmathresult}\,mm (Höhe)};
        \draw[measure] (0,0) ++(0:-1.5*\measureOffSet) -- ++(270:\Height/4) node[midway,below]
          {\pgfmathparse{10*\Height/4}\pgfmathprintnumber{\pgfmathresult}\,mm};
        \draw[measure2] (0,0) ++(0:-1.5*\measureOffSet) ++(270:\Height/4) -- ++(270:\Height/4);
        \draw[measure2] (0,0) ++(0:-1.5*\measureOffSet) ++(270:2*\Height/4) -- ++(270:\Height/4);
        \draw[measure2] (0,0) ++(0:-1.5*\measureOffSet) ++(270:3*\Height/4) -- ++(270:\Height/4);
      \fi
    \end{tikzpicture}
    \\
    5 – Frontblende unten
  \end{center}
  \newpage
  \begin{center}
    \tikzexternaldisable
      \begin{tikzpicture}[rotate=90]
        \ifshowDetails
          \draw[base] (0,0) rectangle ({\DisplayWidth+2*\DisplayBorder},{-\DisplayHeight-2*\DisplayBorder});
        \fi
        \draw[main] (0,0)
        -- ++ (270:{(\side+\wood/tan(60))/4}) -- ++ (0:\wood)
        -- ++ (270:{(\side+\wood/tan(60))/4}) -- ++ (180:\wood)
        -- ++ (270:{(\side+\wood/tan(60))/4}) -- ++ (0:\wood)
        -- ++ (270:{(\side+\wood/tan(60))/4-2*\wood*cos(60)/sin(60)})
        -- ++ (0:{\DisplayWidth+2*\DisplayBorder-2*\wood})
        -- ++ (90:{(\side+\wood/tan(60))/4-2*\wood*cos(60)/sin(60)}) -- ++ (0:\wood)
        -- ++ (90:{(\side+\wood/tan(60))/4}) -- ++ (180:\wood)
        -- ++ (90:{(\side+\wood/tan(60))/4}) -- ++ (0:\wood)
        -- ++ (90:{(\side+\wood/tan(60))/4})
        -- ++ (180:{\topF/5+\wood}) -- ++(270:\wood)
        -- ++ (180:{\topF/5}) -- ++(90:\wood)
        -- ++ (180:{\topF/5}) -- ++(270:\wood)
        -- ++ (180:{\topF/5}) -- ++(90:\wood)
        -- ++ (180:{\topF/5+\wood})
        ;
        \draw[main] (\DisplayBorder,-\DisplayBorder) rectangle ({\DisplayWidth+\DisplayBorder},{-\DisplayHeight-\DisplayBorder});
      \ifshowDetails
        \node[xshift=-.5\baselineskip,rotate=90] (A) at ({(\DisplayWidth+2*\DisplayBorder)/2},0) {oben};
        \node[xshift=.5\baselineskip,rotate=90] (B) at ({(\DisplayWidth+2*\DisplayBorder)/2},{-\DisplayHeight-2*\DisplayBorder}) {vorne};
        % LINKS
        \draw[measure] (0,\measureOffSet) -- ++ (0:{\topF+2*\wood}) node[midway,below,rotate=-90]
    {\pgfmathparse{10*(\topF+2*\wood)}\pgfmathprintnumber{\pgfmathresult}\,mm\ %
      (davon \pgfmathparse{10*\DisplayWidth}\pgfmathprintnumber{\pgfmathresult}\,mm\ Display-Breite
      und 2\(\times\)\pgfmathparse{10*\DisplayBorder}\pgfmathprintnumber{\pgfmathresult}\,mm\ Display-Rand)};
    \draw[measure] (0,2*\measureOffSet) -- ++(0:{\wood+\topF/5}) node[midway,below,rotate=-90]
      {\pgfmathparse{10*(\wood+\topF/5)}\pgfmathprintnumber{\pgfmathresult}\,mm};
    \draw[measure] (0,2*\measureOffSet) ++ (0:{\wood+\topF/5}) -- ++(0:{\topF/5}) node[midway,below,rotate=-90]
      {\pgfmathparse{10*(\topF/5)}\pgfmathprintnumber{\pgfmathresult}\,mm};
    \draw[measure2] (0,2*\measureOffSet) ++ (0:{\wood+2*\topF/5}) -- ++(0:{\topF/5}) node[midway,below,rotate=-90]
      {\pgfmathparse{10*(\topF/5)}\pgfmathprintnumber{\pgfmathresult}\,mm};
    \draw[measure2] (0,2*\measureOffSet) ++ (0:{\wood+3*\topF/5}) -- ++(0:{\topF/5}) node[midway,below,rotate=-90]
      {\pgfmathparse{10*(\topF/5)}\pgfmathprintnumber{\pgfmathresult}\,mm};
    \draw[measure2] (0,2*\measureOffSet) ++ (0:{\wood+4*\topF/5}) -- ++(0:{\topF/5+\wood})  node[midway,below,rotate=-90]
      {\pgfmathparse{10*(\wood+\topF/5)}\pgfmathprintnumber{\pgfmathresult}\,mm};
    % UNTEN
    \draw[measure] (0,0) ++ (180:.5*\measureOffSet) -- ++ (270:{\side+\wood/tan(60)-2*\wood*cos(60)/sin(60)}) node[midway,below]
      {\pgfmathparse{10*(\side+\wood/tan(60)-2*\wood*cos(60)/sin(60))}%
        \pgfmathprintnumber{\pgfmathresult}\,mm\ %
        (vgl. Seitenansicht, gekürztes unteres Ende, damit die Schräge nicht übersteht)};
    \draw[measure] (0,0) ++ (180:1.5*\measureOffSet) -- ++ (270:{(\side+\wood/tan(60))/4}) node[midway,below]
      {\pgfmathparse{10*(\side+\wood/tan(60))/4}\pgfmathprintnumber{\pgfmathresult}\,mm};
    \draw[measure2] (0,0) ++ (180:1.5*\measureOffSet) ++ (270:{(\side+\wood/tan(60))/4})
      -- ++ (270:{(\side+\wood/tan(60))/4});
    \draw[measure2] (0,0) ++ (180:1.5*\measureOffSet) ++ (270:{2*(\side+\wood/tan(60))/4})
      -- ++ (270:{(\side+\wood/tan(60))/4});
    \draw[measure2] (0,0) ++ (180:1.5*\measureOffSet) ++ (270:{3*(\side+\wood/tan(60))/4})
      -- ++ (270:{(\side+\wood/tan(60))/4-2*\wood*cos(60)/sin(60)}) node[midway,below]
      {\pgfmathparse{10*( (\side+\wood/tan(60))/4 -2*\wood*cos(60)/sin(60))}\pgfmathprintnumber{\pgfmathresult}\,mm};
      \fi
    \end{tikzpicture}
    \\
    6 – Displayplatte
  \end{center}
  \newpage
  \begin{center}  
    \tikzexternaldisable
    \begin{tikzpicture}[rotate=90]
      \ifshowDetails
      \draw[base] (0,0) rectangle ({\DisplayWidth+2*\DisplayBorder-2*\wood},{-\Boxboxheight-\wood-\wood/2});
      \fi
      \draw[main] (0,-\wood)%
        -- ++(0:{-\wood+(\DisplayWidth+2*\DisplayBorder)/4-1})
        -- ++(90:\wood) -- ++ (0:2) -- ++(270:\wood)
        -- ++(0:{\DisplayWidth+2*\DisplayBorder)/4-1})
        -- ++(0:{\DisplayWidth+2*\DisplayBorder)/4-1})
        -- ++(90:\wood) -- ++ (0:2) -- ++(270:\wood)
        -- ++(0:{-\wood+(\DisplayWidth+2*\DisplayBorder)/4-1})
        -- ++(270:{(\Boxboxheight-\wood/2)/2-1})
        -- ++(0:\wood) -- ++(270:2) -- ++(180:\wood)
        -- ++(270:{(\Boxboxheight-\wood/2)/2-1})
        -- ++ (180:{\topF/5}) -- ++(270:\wood)
        -- ++ (180:{\topF/5}) -- ++(90:\wood)
        -- ++ (180:{\topF/5}) -- ++(270:\wood)
        -- ++ (180:{\topF/5}) -- ++(90:\wood)
        -- ++ (180:{\topF/5})
        -- ++(90:{(\Boxboxheight-\wood/2)/2-1})
        -- ++(180:\wood) -- ++(90:2) -- ++(0:\wood)
        -- ++(90:{(\Boxboxheight-\wood/2)/2-1})
      ;
      \ifshowDetails
        \node[xshift=-.5\baselineskip,rotate=90] (A) at ({(\DisplayWidth+2*\DisplayBorder)/2},0) {top};
        \node[xshift=.5\baselineskip,rotate=90] (B) at ({(\DisplayWidth+2*\DisplayBorder)/2},{-\wood-\wood/2-\Boxboxheight}) {bottom};
    \draw[measure] (0,\measureOffSet) -- ++ (0:{\topF}) node[midway,below,rotate=-90]
    {\pgfmathparse{10*(\topF)}\pgfmathprintnumber{\pgfmathresult}\,mm};
    \draw[measure] (0,2*\measureOffSet) -- ++ (0:{(\DisplayWidth+2*\DisplayBorder)/4-1-\wood}) node[midway,below,rotate=-90]
      {\pgfmathparse{10*((\DisplayWidth+2*\DisplayBorder)/4-1-\wood)}\pgfmathprintnumber{\pgfmathresult}\,mm};
    \draw[measure] (0,2*\measureOffSet) ++ (0:{(\DisplayWidth+2*\DisplayBorder)/4-1-\wood}) -- ++(0:2) node[midway,below,rotate=-90]
      {\pgfmathparse{20}\pgfmathprintnumber{\pgfmathresult}\,mm};
    \draw[measure] (0,2*\measureOffSet) ++ (0:{(\DisplayWidth+2*\DisplayBorder)/4+1-\wood}) -- ++(0:{(\DisplayWidth+2*\DisplayBorder)/2-2}) node[midway,below,rotate=-90]
      {\pgfmathparse{10*( (\DisplayWidth+2*\DisplayBorder)/2-2)}\pgfmathprintnumber{\pgfmathresult}\,mm};
    \draw[measure] (0,2*\measureOffSet) ++ (0:{(\DisplayWidth+2*\DisplayBorder)/4+1-\wood+(\DisplayWidth+2*\DisplayBorder)/2-2}) -- ++(0:2) node[midway,below,rotate=-90]
      {\pgfmathparse{20}\pgfmathprintnumber{\pgfmathresult}\,mm};
    \draw[measure] (0,2*\measureOffSet) ++ (0:{3*(\DisplayWidth+2*\DisplayBorder)/4+1-\wood}) -- ++(0:{(\DisplayWidth+2*\DisplayBorder)/4-1-\wood}) node[midway,below,rotate=-90]
      {\pgfmathparse{10*((\DisplayWidth+2*\DisplayBorder)/4-1-\wood)}\pgfmathprintnumber{\pgfmathresult}\,mm};
    \draw[measure] (0,3*\measureOffSet) -- ++(0:{\topF/5}) node[midway,below,rotate=-90]
      {\pgfmathparse{10*(\topF/5)}\pgfmathprintnumber{\pgfmathresult}\,mm};
    \draw[measure2] (0,3*\measureOffSet) ++ (0:{\topF/5}) -- ++(0:{\topF/5});
    \draw[measure2] (0,3*\measureOffSet) ++ (0:{2*\topF/5}) -- ++(0:{\topF/5});
    \draw[measure2] (0,3*\measureOffSet) ++ (0:{3*\topF/5}) -- ++(0:{\topF/5});
    \draw[measure2] (0,3*\measureOffSet) ++ (0:{4*\topF/5}) -- ++(0:{\topF/5});
    \draw[measure] (-\measureOffSet,-\wood) --++ (270:{\Boxboxheight}) node[midway, below]
      {\pgfmathparse{10*(\Boxboxheight)}\pgfmathprintnumber{\pgfmathresult}\,mm (innere Höhe)};
    \draw[measureW] (-2*\measureOffSet,0) --++ (270:\wood);
    \draw[measure] (-2*\measureOffSet,-\wood) --++ (270:{(\Boxboxheight-\wood/2)/2-1}) node[midway, below]
      {\pgfmathparse{10*((\Boxboxheight-\wood/2)/2-1)}\pgfmathprintnumber{\pgfmathresult}\,mm};
    \draw[measure] (-2*\measureOffSet,0) ++ (270:{(\Boxboxheight-\wood/2)/2-1+\wood}) -- ++ (270:2) node[midway, below]
      {\pgfmathparse{20}\pgfmathprintnumber{\pgfmathresult}\,mm};
    \draw[measure] (-2*\measureOffSet,-\wood) ++ (270:{(\Boxboxheight-\wood/2)/2+1})
      --++ (270:{(\Boxboxheight-\wood/2)/2-1}) node[midway, below]
      {\pgfmathparse{10*((\Boxboxheight-\wood/2)/2-1)}\pgfmathprintnumber{\pgfmathresult}\,mm};
    \draw[measureW] (-2*\measureOffSet,{-\wood/2-\Boxboxheight}) --++ (270:\wood);
      \fi
    \end{tikzpicture}
    \\
    7 – innere Box -- Rückseite
  \end{center}
  \newpage
  \begin{center}  
    \tikzexternaldisable
    \begin{tikzpicture}[rotate=90]
      \ifshowDetails
      \draw[base] (0,0) rectangle ({\DisplayWidth+2*\DisplayBorder-2*\wood},{-\wood-\wood/2-\Boxboxdepth});
      \fi
      \draw[main] (0,-\wood)%
        -- ++(0:{-\wood+(\DisplayWidth+2*\DisplayBorder)/4-1})
        -- ++(90:\wood) -- ++ (0:2) -- ++(270:\wood)
        -- ++(0:{\DisplayWidth+2*\DisplayBorder)/4-1})
        -- ++(0:{\DisplayWidth+2*\DisplayBorder)/4-1})
        -- ++(90:\wood) -- ++ (0:2) -- ++(270:\wood)
        -- ++(0:{-\wood+(\DisplayWidth+2*\DisplayBorder)/4-1})
        -- ++(270:{(\Boxboxdepth-\wood/2)/2-1})
        -- ++(0:\wood) -- ++(270:2) -- ++(180:\wood)
        -- ++(270:{(\Boxboxdepth+\wood/2)/2-1})
        -- ++ (180:{\topF/5}) -- ++(90:\wood)
        -- ++ (180:{\topF/5}) -- ++(270:\wood)
        -- ++ (180:{\topF/5}) -- ++(90:\wood)
        -- ++ (180:{\topF/5}) -- ++(270:\wood)
        -- ++ (180:{\topF/5})
        -- ++(90:{(\Boxboxdepth+\wood/2)/2-1})
        -- ++(180:\wood) -- ++(90:2) -- ++(0:\wood)
        -- ++(90:{(\Boxboxdepth-\wood/2)/2-1})
      ;
      \ifshowDetails
        \node[xshift=-.5\baselineskip,rotate=90] (A) at ({(\DisplayWidth+2*\DisplayBorder)/2},0) {back};
        \node[xshift=.5\baselineskip,rotate=90] (B) at ({(\DisplayWidth+2*\DisplayBorder)/2},{-\wood-\wood/2-\Boxboxdepth}) {front};
    \draw[measure] (0,\measureOffSet) -- ++ (0:{\topF}) node[midway,below,rotate=-90]
    {\pgfmathparse{10*(\topF)}\pgfmathprintnumber{\pgfmathresult}\,mm};
    \draw[measure] (0,2*\measureOffSet) -- ++ (0:{(\DisplayWidth+2*\DisplayBorder)/4-1-\wood}) node[midway,below,rotate=-90]
      {\pgfmathparse{10*((\DisplayWidth+2*\DisplayBorder)/4-1-\wood)}\pgfmathprintnumber{\pgfmathresult}\,mm};
    \draw[measure] (0,2*\measureOffSet) ++ (0:{(\DisplayWidth+2*\DisplayBorder)/4-1-\wood}) -- ++(0:2) node[midway,below,rotate=-90]
      {\pgfmathparse{20}\pgfmathprintnumber{\pgfmathresult}\,mm};
    \draw[measure] (0,2*\measureOffSet) ++ (0:{(\DisplayWidth+2*\DisplayBorder)/4+1-\wood}) -- ++(0:{(\DisplayWidth+2*\DisplayBorder)/2-2}) node[midway,below,rotate=-90]
      {\pgfmathparse{10*( (\DisplayWidth+2*\DisplayBorder)/2-2)}\pgfmathprintnumber{\pgfmathresult}\,mm};
    \draw[measure] (0,2*\measureOffSet) ++ (0:{(\DisplayWidth+2*\DisplayBorder)/4+1-\wood+(\DisplayWidth+2*\DisplayBorder)/2-2}) -- ++(0:2) node[midway,below,rotate=-90]
      {\pgfmathparse{20}\pgfmathprintnumber{\pgfmathresult}\,mm};
    \draw[measure] (0,2*\measureOffSet) ++ (0:{3*(\DisplayWidth+2*\DisplayBorder)/4+1-\wood}) -- ++(0:{(\DisplayWidth+2*\DisplayBorder)/4-1-\wood}) node[midway,below,rotate=-90]
      {\pgfmathparse{10*((\DisplayWidth+2*\DisplayBorder)/4-1-\wood)}\pgfmathprintnumber{\pgfmathresult}\,mm};
    \draw[measure] (0,3*\measureOffSet) -- ++(0:{\topF/5}) node[midway,below,rotate=-90]
      {\pgfmathparse{10*(\topF/5)}\pgfmathprintnumber{\pgfmathresult}\,mm};
    \draw[measure2] (0,3*\measureOffSet) ++ (0:{\topF/5}) -- ++(0:{\topF/5});
    \draw[measure2] (0,3*\measureOffSet) ++ (0:{2*\topF/5}) -- ++(0:{\topF/5});
    \draw[measure2] (0,3*\measureOffSet) ++ (0:{3*\topF/5}) -- ++(0:{\topF/5});
    \draw[measure2] (0,3*\measureOffSet) ++ (0:{4*\topF/5}) -- ++(0:{\topF/5});
    \draw[measure] (-\measureOffSet,-\wood) --++ (270:{\Boxboxdepth}) node[midway, below]
      {\pgfmathparse{10*(\Boxboxdepth)}\pgfmathprintnumber{\pgfmathresult}\,mm (innere Tiefe)};
    \draw[measureW] (-2*\measureOffSet,0) --++ (270:\wood);
    \draw[measure] (-2*\measureOffSet,-\wood) --++ (270:{(\Boxboxdepth-\wood/2)/2-1}) node[midway, below]
      {\pgfmathparse{10*((\Boxboxdepth-\wood/2)/2-1)}\pgfmathprintnumber{\pgfmathresult}\,mm};
    \draw[measure] (-2*\measureOffSet,0) ++ (270:{(\Boxboxdepth-\wood/2)/2-1+\wood}) -- ++ (270:2) node[midway, below]
      {\pgfmathparse{20}\pgfmathprintnumber{\pgfmathresult}\,mm};
    \draw[measure] (-2*\measureOffSet,-\wood) ++ (270:{(\Boxboxdepth-\wood/2)/2+1})
      --++ (270:{(\Boxboxdepth-\wood/2)/2-1}) node[midway, below]
      {\pgfmathparse{10*((\Boxboxdepth-\wood/2)/2-1)}\pgfmathprintnumber{\pgfmathresult}\,mm};
    \draw[measureW] (-2*\measureOffSet,{-\wood/2-\Boxboxdepth}) --++ (270:\wood);
      \fi
    \end{tikzpicture}
    \\
    8 – Boxbox-Unterseite
  \end{center}
\end{document}

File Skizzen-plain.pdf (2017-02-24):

# Die IceBoxWoodBox

An felgender erster Grafik sind alle Werte verzeichnet, die sich per Variable ändern lassen: Tiefe (oben) Höhe (vorne), Displayhöhe, (in dieser Grafik nicht enthalten: Displaybreite), Holzdicke, sowie Höhe und Tiefe der inneren Box.

# icebox.nobreakspace.org

Klick dir ’ne Mate.

5 – Frontblende unten

6 – Displayplatte

7 – innere Box – Rückseite

8 – Boxbox-Unterseite

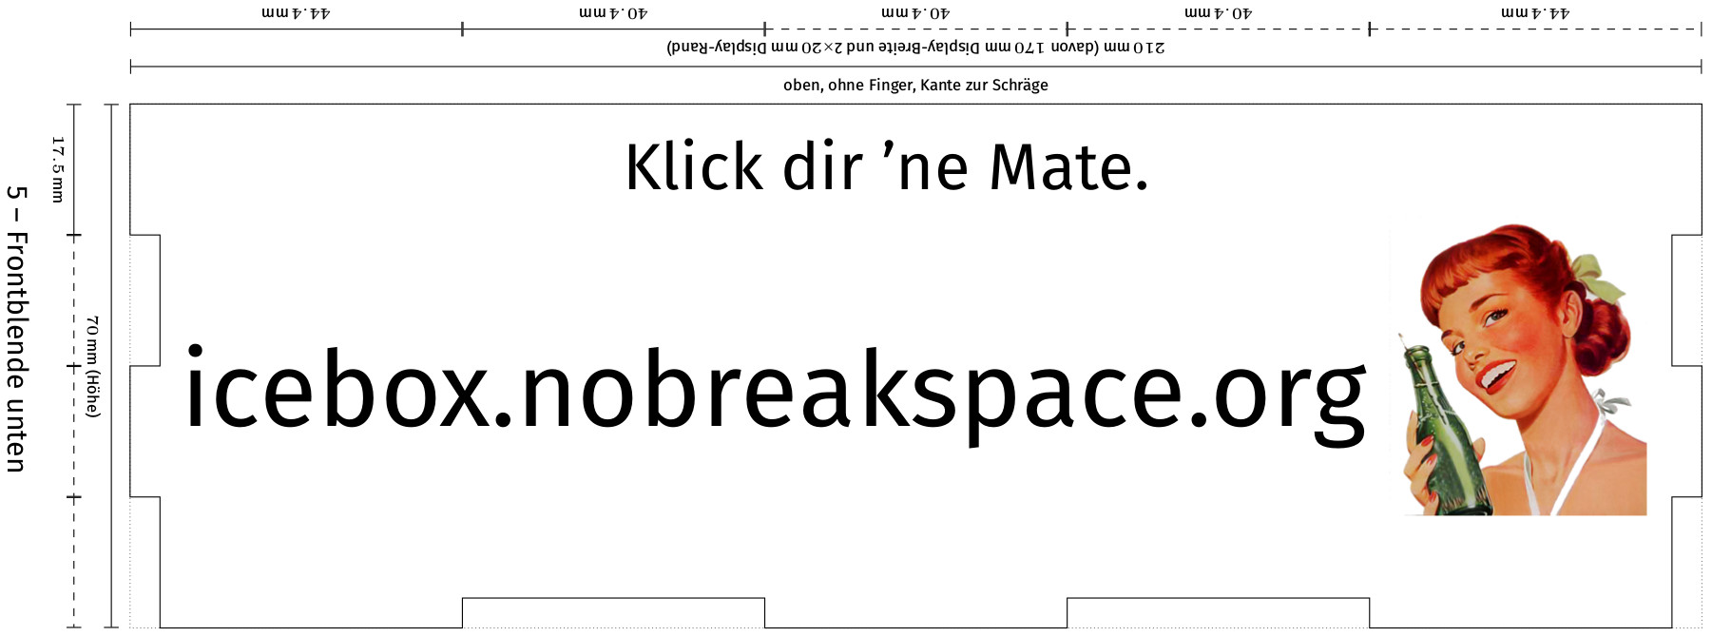
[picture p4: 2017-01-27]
Fotos/front-entwurf1.jpg

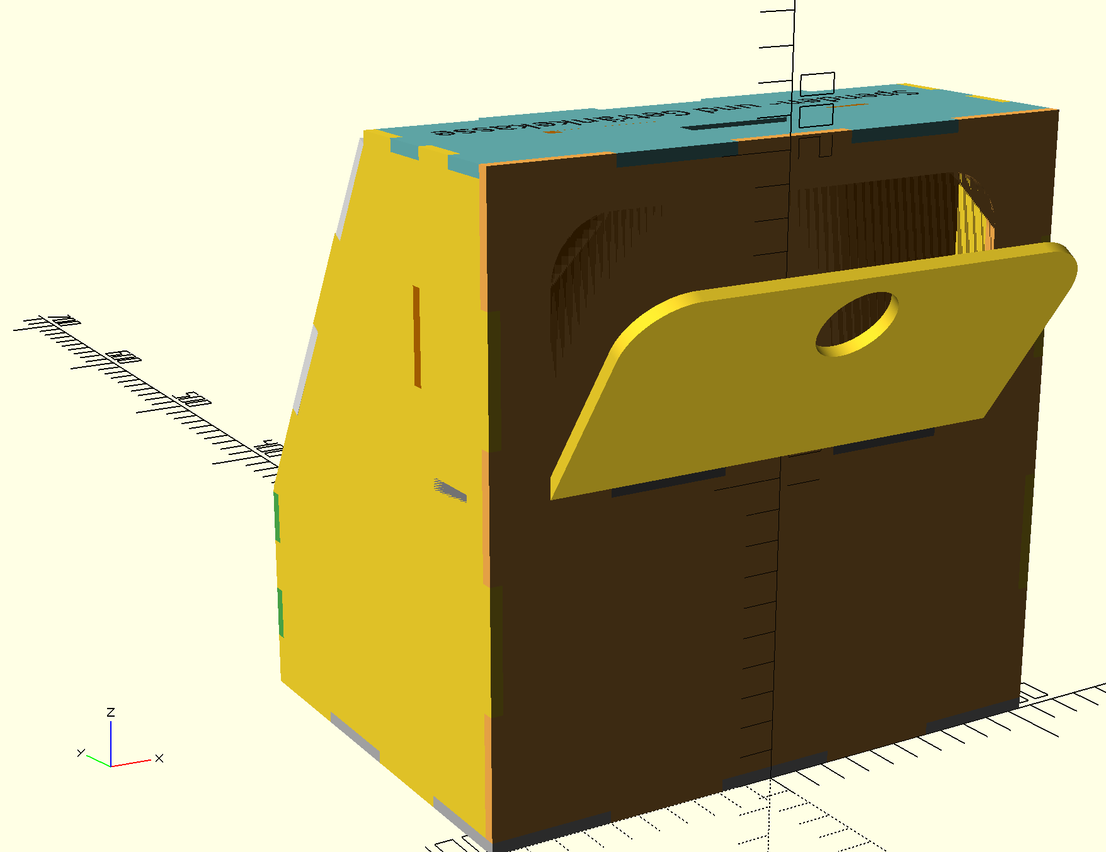
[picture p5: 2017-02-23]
openSCAD/Proto1b.png

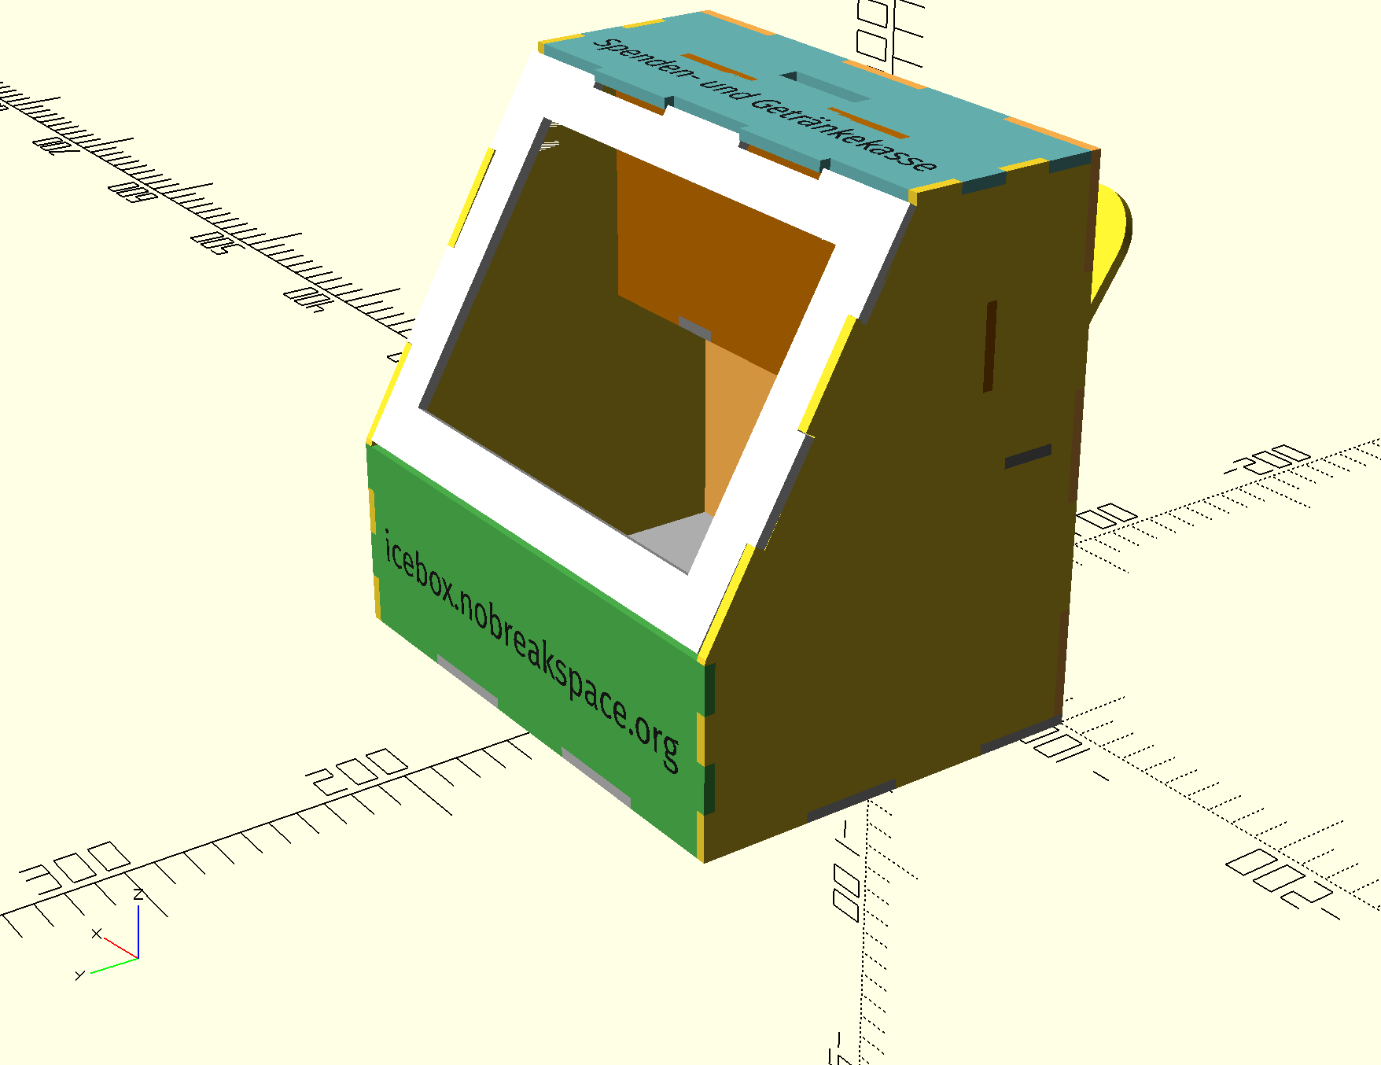
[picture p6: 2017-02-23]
openSCAD/Proto1c.png

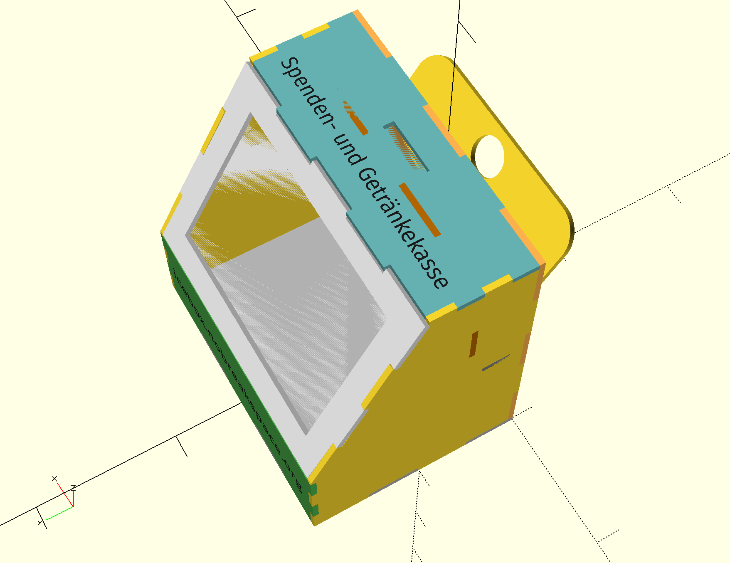
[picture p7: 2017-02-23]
openSCAD/Proto1.png

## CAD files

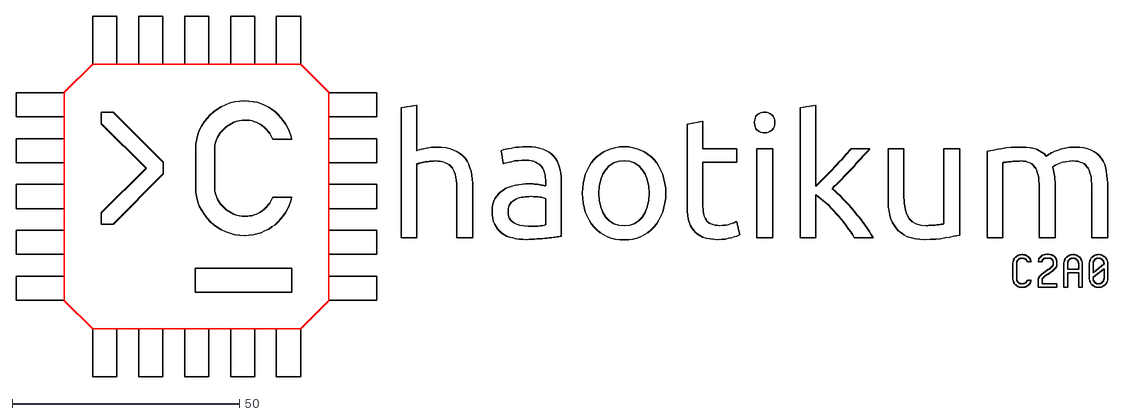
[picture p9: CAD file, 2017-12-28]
img/chaotikum-logo.dxf
240.0 x 79.3

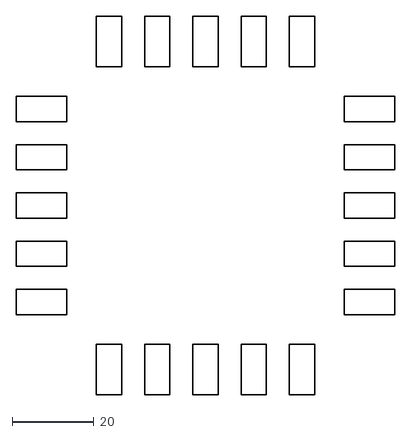
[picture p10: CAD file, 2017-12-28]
openSCAD/Chaotikum-Logo/Parts/D-Feet.dxf
92.8 x 92.8

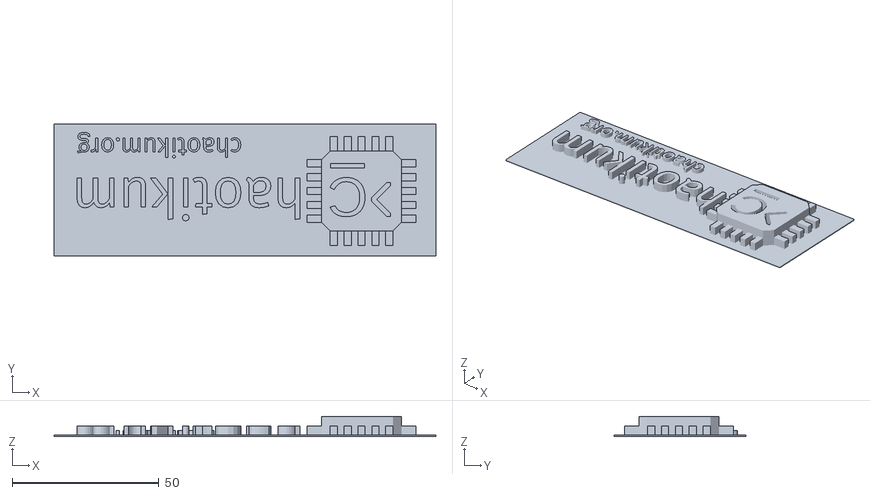
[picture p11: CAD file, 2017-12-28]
openSCAD/Logo.stl
130.0 x 45.0 x 6.90

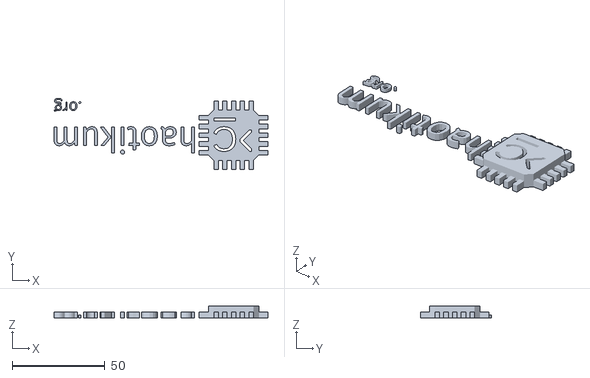
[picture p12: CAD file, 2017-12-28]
openSCAD/Logoparts/chaotikum-and-feet.stl
115.4 x 38.5 x 6.40

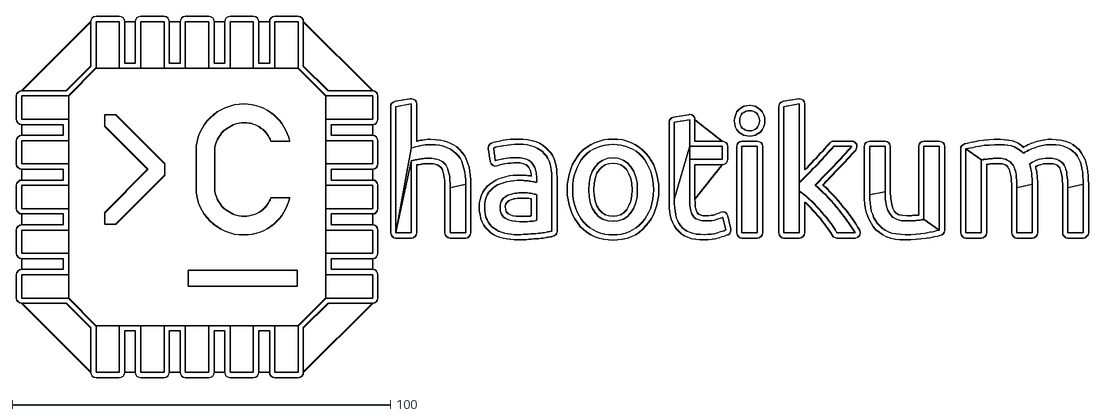
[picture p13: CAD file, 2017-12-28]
openSCAD/Parts/4-Base.dxf
283.5 x 95.5

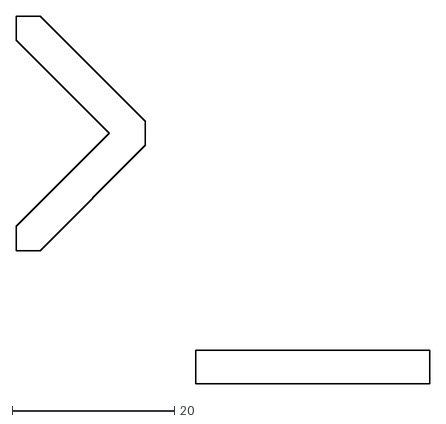
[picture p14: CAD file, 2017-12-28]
openSCAD/Chaotikum-Logo/Parts/B-Holes.dxf
51.0 x 45.3

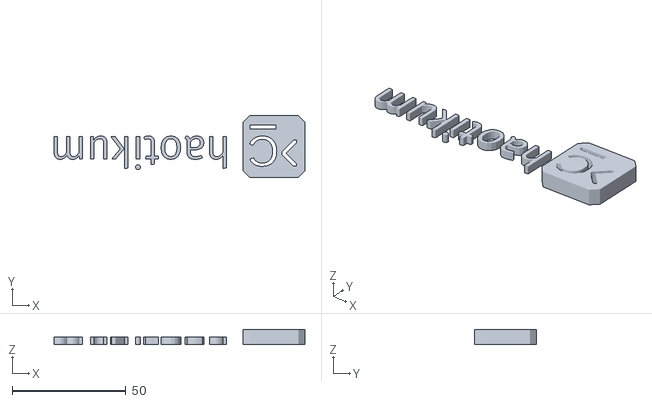
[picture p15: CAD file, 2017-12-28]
openSCAD/Logoparts/chaotikum.stl
110.4 x 27.2 x 6.40

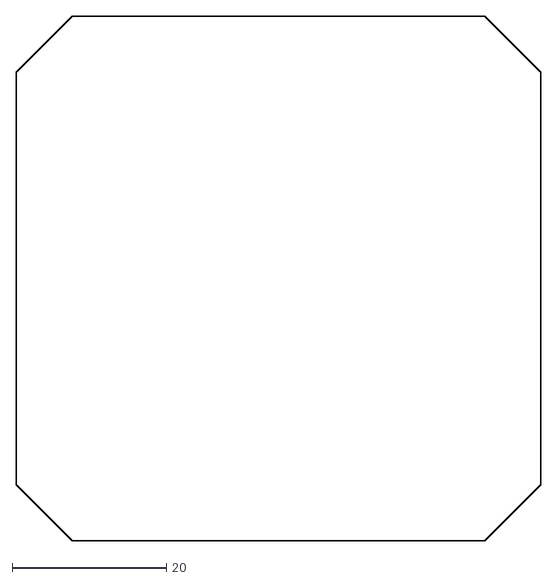
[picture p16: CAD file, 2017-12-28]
openSCAD/Chaotikum-Logo/Parts/A-Base.dxf
68.0 x 68.0

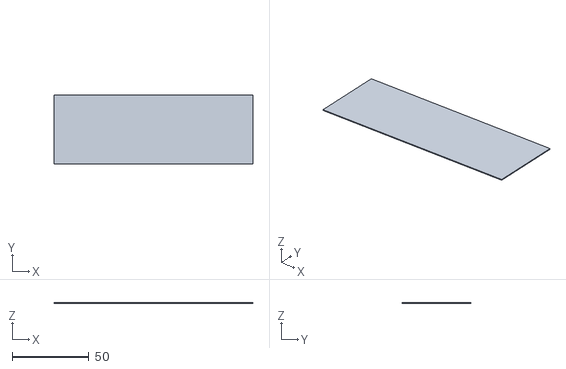
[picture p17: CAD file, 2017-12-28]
openSCAD/Logoparts/plate.stl
130.0 x 45.0 x 0.5

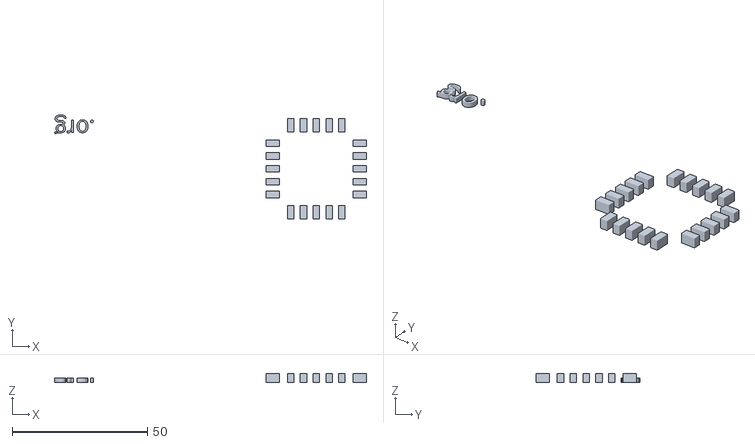
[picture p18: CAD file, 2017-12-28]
openSCAD/Logoparts/feet.stl
115.3 x 38.5 x 3.20

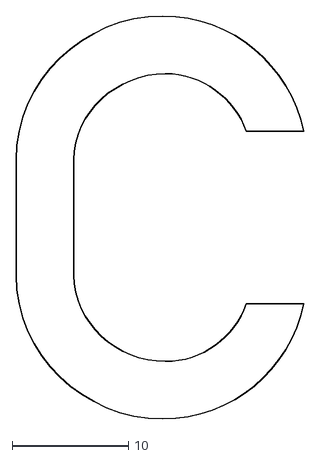
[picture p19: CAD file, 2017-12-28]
openSCAD/Parts/C-C.dxf
24.7 x 34.6

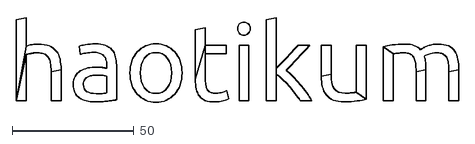
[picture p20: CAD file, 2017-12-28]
openSCAD/Parts/E-haotikum.dxf
181.7 x 34.6

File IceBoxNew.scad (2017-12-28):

/*
 * Vizuals
 */
flat = false;
spacing = 10;

/*
 *    Measurements – all refer to _outer_ measurements
 */
displayWidth = 170; //Width of the display-Slot
displayHeight = 110; //Hewigh of the Display-Slot
displayBorder = 20; //Border around the display
depth = 70;  // Depth behind end of upper end of display plate
height = 70; // Height below display plate
iBHeight = 100; //inner Box Height
iBDepth = 40; //Inner Box depth
slotWidth = 40;
slotDepth = 7.5;
wW = 4;
cRadius = 20;


//Dont change these values
FrontHeight = displayHeight+2*displayBorder;
sideHeight = FrontHeight*sin(60);
sideDepth = FrontHeight*cos(60);
width = displayWidth+2*displayBorder;
tDepth = depth+sideDepth;
totalHeight = sideHeight+height;


bottomPlate();
echo(genSide(a=0,v=[0,tDepth/2],width,1,wW,0,0));
echo(generateSide([rotM(0)*[-width/2,0]+[0,0]],width,0,0,[0,0],0,0,wW,2,true));
/* Module for the bottom Plate */
module bottomPlate() {
polygon(points = concat(
//    [-width/2, tDepth/2],  [width/2, tDepth/2], //Front:
    generateSide([rotM(0)*[-width/2,0]+[0,tDepth/2-wW]],width,0,0,[0,tDepth/2-wW],0,0,wW,2,true),
//    generateSide(a=0,v=[-width/2,tDepth/2],sLe=0,sRi=0,h=wW,fC=4),
    [[width/2,  tDepth/2],  [width/2,-tDepth/2],
    [width/2, -tDepth/2], [-width/2,-tDepth/2],
    [-width/2,-tDepth/2], [-width/2, tDepth/2]
    ]
    ));
}
/*
 * Helper to generate a side
 * a – direction of the line
 * v - shift (starting point)
 * 
 */
function genSide(a,v,sL,fC,h=wW,sLe=0,sRi=0,eP=true) = generateSide([rotM(a)*[-(sL-sLe)/2,0]+v],
    sL,i,a,v,sLe,sRi,h,fC,eP);   
//Recursively generate fC toothes
function generateSide(pL,sL,i,a,v,sLe,sRi,h,fC,eP) = (i==fC) ? ((eP==true) ? concat(pL,[rotM(a)*[(sL-sRi)/2,0]+v]): [])
    : generateSide(concat(pL,[
        rotM(a)*[-sL/2+(2*i+1)*sL/(2*fC+1),0]+v, rotM(a)*[-sL/2+(2*i+1)*sL/(2*fC+1),h]+v,
        rotM(a)*[-sL/2+(2*i+2)*sL/(2*fC+1),h]+v, rotM(a)*[-sL/2+(2*i+2)*sL/(2*fC+1),0]+v]),
        sL,i+1,a,v,sLe,sRi,h,fC,eP);
function rotM(a) = [[cos(a),sin(a)],[-sin(a),cos(a)]];

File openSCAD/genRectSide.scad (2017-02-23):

/* genLine() generate a Line with Fingers
 * startPos    - start position
 * endPos      - endposition
 * startOffSet - start with an offset beofre first finger
 * endOffset   - extend last line with offset
 * fC          - fingerCount - number of fingers
 * fH          - finger height - height of fingers
 * cO          - count Odd - (0) each finger is followed by a line segment of same length (even number of segments); (1) odd number of segments 
 * sWF         - startWithFinger - whether to start with a finger (1) or not (0)
 */
 
function genLine(startPos,endPos, startOffset=0, endOffset=0, fC=3, fH=1, cO=0, sWF=0,fTR=1) = 
    genRectSide(a=-atan2(endPos[1]-startPos[1], endPos[0]-startPos[0]), v=startPos, sStart=-startOffset, sEnd=-endOffset, fTR=fTR, fH=fH,
    fL=( sqrt( pow( (startPos[0]-endPos[0]), 2) + pow( (startPos[1]-endPos[1]), 2) ) -startOffset-endOffset)/(2*fC+cO),
    fC=fC, cO=cO, sWF=sWF);

/*
 * genRectSide() generate Rectangle Side in the xy-plane
 * a      - starting angle
 * v      - shift startpoint from (0,0) to v
 * sStart - shorten the startLine
 * sEnd   - shorten EndLine
 * fTR    - (1) [f]irst corner [t]urns [r]ight (0) first corner turns left
 * fH     - [f]inger[H]eight : height between [f]inger and inner line
 * fC     - [f]inger[C]ount  : number of Fingers
 * fL     - [f]inger[L]ength : length of a Finger
 * cO     - [c]ount [O]dd : each finger is followed by an off-part of same length. This variable
 *                          (0) ends after fC fingers without a finger (1) with a finger                        
 *
 */
function genRectSide(a=0, v=[0,0], sStart=0, sEnd=0, fTR=1, fH=1, fL=2, fC=3, cO=0,sWF=0) =
    genRectSideRec( ((sWF==1) ? [v] : []),a,v,sStart,sEnd,fTR,fH,fL,cO,fC,0);
function genRectSideRec(list,a,v,sStart,sEnd,fTR,fH,fL,cO,upperLimit,cnt) = (cnt==upperLimit)
    ? concat(list, (cO==1) ? [rotM(a)*[(2*cnt)*fL,0]+v, rotM(a)*[(2*cnt+1)*fL-sEnd,0]+v] : [])
    : genRectSideRec(concat(list, // add one finger and its fopllowing off
        [ //2*fTR-1 is 1 for right, -1 for left
        rotM(a)*[2*cnt*fL,0]+v, rotM(a)*[(2*cnt+1)*fL,0]+v,
        rotM(a)*[(2*cnt+1)*fL,(2*fTR-1)*fH]+v, rotM(a)*[(2*cnt+2)*fL - ( ((cO==0)&&(cnt==(upperLimit-1)))?sEnd:0), (2*fTR-1)*fH]+v
        ]),a,v,sStart,sEnd,fTR,fH,fL,cO,upperLimit,cnt+1);
function rotM(a) = [[cos(a),sin(a)],[-sin(a),cos(a)]];

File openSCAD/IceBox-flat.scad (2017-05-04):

include <genRectSide.scad>;
/*
 *    Maße
 */
displayWidth = 170;
displayHeight = 110;
displayBorder = 20;
depth = 70;  // Depth behind end of upper end of display plate
height = 70; // Height below display plate
iBHeight = 100;
iBDepth = 40;
slotWidth = 40;
slotDepth = 7.5;
wW = 4;
cRadius = 20;

//Visually
extend = 2*wW; //0=closed, otherwise whis is the distance between plates
//Dont change these values
side = displayHeight+2*displayBorder;
sideHeight = side*sin(60);
sideWidth = side*cos(60);
width = displayWidth+2*displayBorder-2*wW;
totalDepth = depth+sideWidth+wW/2;
totalHeight = sideHeight+height;
//Bottom plate
color([.7,.7,.7])
linear_extrude(wW)
polygon(points=concat(
    genLine([-width/2,0],[-width/2,totalDepth],fH=wW,fC=2,fTR=0),
    genLine([-width/2,totalDepth],[width/2,totalDepth],fH=wW,fC=2,cO=1),
    genLine([width/2,totalDepth],[width/2,0],fH=wW,fC=2),
    genLine([width/2+wW,0],[-width/2,0],fH=wW,fC=2,cO=1,fTR=0)
    ));
// Rear
color([1,.7,.3]) translate([0,-totalHeight-extend])
linear_extrude(wW)
    difference() {
        polygon(points=concat(
        genLine([-width/2,0],[-width/2,totalHeight],fH=wW,fC=2, cO=1,fTR=0),
        genLine([-width/2,totalHeight],[width/2+wW,totalHeight],fH=wW,fC=2,cO=1),
        genLine([width/2+wW,totalHeight],[width/2+wW,0],fH=wW,fC=2, cO=1, fTR=0),
        genLine([width/2+wW,0],[-width/2,0],fH=wW,fC=2,cO=1,fTR=0)
        ));
        //holes for inner plate
        translate([0,iBHeight]) rotate(90,[1,0,0])
            polygon(points=concat(
            [[width/2,3*wW]],
            genLine([width/2,wW],[-width/2,wW],fH=1.2*wW,fC=2,cO=1,fTR=1),
            [[-width/2,3*wW]]
          ));
        //Hole for Klappe
        translate([0,iBHeight-wW,0]) rotate(180,[0,0,1])
        hull() {
            polygon(points=[[-width/2+displayBorder,0],[width/2-displayBorder,0],
              [width/2-displayBorder, iBHeight/2],[-width/2+displayBorder,iBHeight/2]]);
            translate([-width/2+displayBorder+cRadius, iBHeight-displayBorder-cRadius, 0])
            circle(r=cRadius,$fn=360);
            translate([width/2-displayBorder-cRadius, iBHeight-displayBorder-cRadius, 0])
    circle(r=cRadius,$fn=360);
};
}

//Top
color([.4,.7,.7])
translate([0,-totalHeight-depth-2*extend])
linear_extrude(wW)
difference() {
polygon(points=concat( //2*wW on each because they all turn fingers inwards
    genLine([-width/2,0],[-width/2,depth],fH=wW,fC=2,fTR=0),
    genLine([-width/2,depth],[width/2+wW,depth],fH=wW,fC=2,cO=1),
    genLine([width/2,depth],[width/2,0],fH=wW,fC=2),
    genLine([width/2+wW,0],[-width/2,0],fH=wW,fC=2,cO=1)
    ));
translate([wW/2,0,0])
    polygon(points=[[-slotWidth/2,1/3*depth-slotDepth/2],
             [-slotWidth/2,1/3*depth+slotDepth/2],
             [slotWidth/2,1/3*depth+slotDepth/2],
             [slotWidth/2,1/3*depth-slotDepth/2]]);
translate([0,iBDepth]) rotate(90,[1,0,0])
    polygon(points=concat(
     [[width/2,0]],
     genLine([width/2,wW],[-width/2+wW,iBHeight-wW],fH=1*wW,fC=2,cO=1,fTR=0)
     [[-width/2,0]]));
}

# translate([0,iBDepth]) rotate(90,[1,0,0])
    polygon(points=concat(
     [[width/2,0]],
     genLine([width/2,wW],[-width/2+wW,iBHeight-wW],fH=1*wW,fC=2,cO=1,fTR=0)
     [[-width/2,0]]));

//Front
color([.3,.7,.3])
translate([0,totalDepth+extend,0])
linear_extrude(wW)
polygon(points=concat( //2*wW on each because they all turn fingers inwards
    genLine([-width/2+wW,0],[-width/2+wW,height],fH=wW,fC=2,fTR=1), //right
    genLine([-width/2,height],[width/2,height],fH=0,fC=2,cO=1), //top
    genLine([width/2+wW,height],[width/2+wW,0],fH=wW,fC=2,fTR=0), //left
    genLine([width/2,0],[-width/2,0],fH=wW,fC=2,cO=1,fTR=0)
    ));
//Display
sideT = side + wW/tan(60)-2*wW*cos(60)/sin(60);
color([.9,.9,.9])
translate([0,depth+totalDepth+sideT/2+2*extend,wW])
rotate(180,[1,0,0])
linear_extrude(wW)
difference() {
polygon(points=concat(
    genLine([-width/2,-sideT/2],[-width/2,sideT/2],fH=wW,fC=2,fTR=0), //top
    genLine([-width/2,sideT/2],[width/2,sideT/2],fH=0,fC=2,cO=1),
    genLine([width/2,sideT/2],[width/2,-sideT/2-wW*cos(60)/2],fH=wW,fC=2),
    genLine([width/2+wW,-sideT/2-wW*cos(60)/2],[-width/2,-sideT/2-wW*cos(60)/2],fH=wW,fC=2,cO=1,fTR=0)
    ));
translate([wW/2,0])
polygon(points=[[-width/2+displayBorder,-side/2+displayBorder],
    [width/2-displayBorder,-side/2+displayBorder],
    [width/2-displayBorder,side/2-displayBorder],
    [-width/2+displayBorder,side/2-displayBorder]]); 
}
//Side plate
translate([width/2+extend,wW]) rotate(0,[0,1,0]) sidePlate();
translate([-width/2+wW-extend,wW,wW]) rotate(180,[0,1,0]) sidePlate();

module sidePlate() {
linear_extrude(wW)
difference() {
  polygon(points=concat(
    genLine([0,0],[totalHeight,0],fH=wW,fC=2, cO=1,fTR=0)
    +[[0,0],[wW,0],[wW,0],[wW,0],[wW,0],[wW,0],[wW,0],[wW,0],[wW,0],[wW,0]]
    , //Rear + trckshift
    genLine([totalHeight,0],[totalHeight,depth],fH=wW,fC=2,fTR=0), //top
    genLine([totalHeight,depth],[height,totalDepth-wW],fH=wW,fC=2,fTR=0)
    +[[0,0],[0,0],[0,0],[0,0],[0,0],[0,0],[0,0],[0,0]], //Display
    [[height,totalDepth]],
    genLine([height,totalDepth-wW],[0,totalDepth-wW],fH=wW,fC=2,fTR=0)
    ,
    //front + trickshift first
    genLine([0,totalDepth],[0,0],fH=wW,fC=2,fTR=1)
    -[[0,0],[0,wW],[0,wW],[0,wW],[0,wW],[0,wW],[0,wW],[0,0]]
    //bottom line + trickshift
    ));
    translate([totalHeight-iBHeight+wW,iBDepth,0])
    polygon(points=[[29,0],[29,-wW],[59,-wW],[59,0]]);
    translate([totalHeight-iBHeight+2*wW,0,0])
    polygon(points=
    [[0,9],[-wW,9],[-wW,29],[0,29]]);
}
};

//Inner bottom
color([.5,.5,.5])
translate([-width-wW-extend,-iBDepth-extend,0])
linear_extrude(wW)
polygon(points=concat(//side
    [[-width/2+wW,0],[-width/2+wW,9],[-width/2,9],[-width/2,29],[-width/2+wW,29],
        [-width/2+wW,iBDepth-wW]],
        //front
    [[-width/2+wW,iBDepth-wW],
     [-width/2+38.5,iBDepth-wW],[-width/2+38.5,iBDepth],
     [-width/2+58.5,iBDepth],[-width/2+58.5,iBDepth-wW],
     [width/2-58.5,iBDepth-wW],[width/2-58.5,iBDepth],
     [width/2-38.5,iBDepth],[width/2-38.5,iBDepth-wW],
     [width/2-wW,iBDepth-wW]
    ],
    [[width/2,iBDepth-wW],[width/2,29],[width/2+wW,29],[width/2+wW,9],
     [width/2,9],[width/2,0]],
    genLine([width/2,0],[-width/2,0],fH=wW,fC=2,cO=1,fTR=1)
    ));

//Inner front
color([.7,.4,0])
translate([width+wW+extend,-iBHeight-extend,0]) rotate(0,[1,0,0])
linear_extrude(wW)
    polygon(points=concat(//side
     [[-width/2+wW,iBHeight-wW],[-width/2+wW,59],[-width/2,59],[-width/2,29],
     [-width/2+wW,29],[-width/2+wW,0]],
        //front
    [[-width/2,0],
     [-width/2+38.5,0],[-width/2+38.5,wW],
     [-width/2+58.5,wW],[-width/2+58.5,0],
     [width/2-58.5,0],[width/2-58.5,wW],
     [width/2-38.5,wW],[width/2-38.5,0],
     [width/2,0]
    ],
        [[width/2,iBHeight-wW],[width/2,59],[width/2+wW,59],[width/2+wW,29],
     [width/2,29],[width/2,-wW]],
     genLine([width/2,iBHeight-wW],[-width/2+wW,iBHeight-wW],fH=wW,fC=2,cO=1,fTR=0)
    ));
//Klappe
translate([-width+displayBorder-extend,-totalHeight+height+displayBorder,wW]) rotate(180,[1,0,0])
linear_extrude(wW)
difference() {
hull() {
 polygon(points=[[-width/2+displayBorder,0],[width/2-displayBorder,0],
    [width/2-displayBorder, iBHeight/2],[-width/2+displayBorder,iBHeight/2]]);
translate([-width/2+displayBorder+cRadius, iBHeight-displayBorder-cRadius, 0])
    circle(r=cRadius,$fn=360);
translate([width/2-displayBorder-cRadius, iBHeight-displayBorder-cRadius, 0])
    circle(r=cRadius,$fn=360);
};
translate([0, iBHeight-displayBorder-1*cRadius, 0])
    circle(r=2*cRadius/3,$fn=360);
}

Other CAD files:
openSCAD/IceBox.scad
openSCAD/Chaotikum-Logo/Logo.scad
openSCAD/Chaotikum-Logo/LogoKekse.scad
openSCAD/Chaotikum-Logo/LogoKekse2.scad
openSCAD/IceBoxNew.scad
openSCAD/Logo.scad
openSCAD/T.scad

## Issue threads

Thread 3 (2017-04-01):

Two holes of the inner front missing in the top plate

kellertuer, 2017-04-01:
Before going into laser, this should be fixed.

kellertuer, 2017-05-04:
Fixed in the code refinement these days.

Closed 2017-05-04.

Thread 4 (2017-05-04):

Barcode-Scanner

TVLuke, 2017-05-04:
An dem Pi in der Icebox hängt per USB ein Barcode-Scanner. Das Kabel ist gefühlt ca. 1 m lang und muss irgendwie aus der Box raus. Der Scanner muss wohl nicht unbedingt an der Box hängen, da die ja eh sehr weit oben steht und der scanner auch nicht grad klein ist.

kellertuer, 2017-05-04:
Man könnte ja trotzdem wie bei nem alten Telefon an der Seite so ne Gabel machen in der der hängt...

TVLuke, 2017-05-04:
Ja, aber der Scanner ist ca. so hoch wie die box selbst und für kleine Leute liegt das Ding recht hoch...

Aber: Vielleicht hängt man die Box ja auch seitlich an den Kühlschrank, dann wäre es ne andere Sache.

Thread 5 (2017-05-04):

NFC-Reader

TVLuke, 2017-05-04:
An dem Pi in der Icebox hängt ein NFC-Reader. Der sollte möglichst nah am Pi sein heißt, ggf. sollte der in die Box integriert sein. Durch das Holz wird das allerdings nicht funktionieren. Ich habe keine Ahnung wie das gehen soll.

Mindestens muss auch das Kabel aus der Box raus, damit das Gerät daneben liegen kann.

kellertuer, 2017-05-04:
Meine Idee ist (wenn ich das Pad richtig erinnere) dass der hochkant in eine Seite reinpassen sollte, wenn man da n größeres Loch reinlasert und den da an einer Seite der Box rausgucken lässt. Mal auf die Größen warten :)

TVLuke, 2017-05-04:
Das könnte gehen. Visuell wahrscheinlich nicht berauschend, aber von der Funktion her... läuft.

kellertuer, 2017-05-04:
Bin auch für visuell berauschendere Ideen zu haben ;)

kellertuer, 2017-05-04:
Erster Vorschlag ist  im commit (wenn ich nu noch wüsste, wie man die verlinkt).

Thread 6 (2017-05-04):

Raspberry & Cables

kellertuer, 2017-05-04:
Introduce a place for the raspberry at the bottom and a hole for the power supply cable in the back.

kellertuer, 2017-05-04:
First idea in 7ab21f52958b2ecde685d896ac70531cdb86437c.

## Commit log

2017-01-28 prototyp gebastelt; alle Maße stimmen, nun müsst man das lasern.
2017-02-23 First OpenSCAD prototype.
    [IceBox.scad, genRectSide.scad]
2017-02-24 adds a flat version.
    [IceBox-flat.scad]
2017-03-31 fixes the first-2Dthen-3D- approach in all figures.
    [IceBox-flat.scad]
2017-05-03 restart a structured with correct hoiles: Bottom, Front, Side und inner plates.
    [IceBoxNew.scad]
2017-05-03 finishes the IceBox V2 (in first2D then 3D style with all holes!)
    [IceBoxNew.scad]
2017-05-04 arrange flat version.
    [IceBox-flat.scad, IceBox.scad, IceBoxNew.scad]
2017-05-04 hole for card reader | hole for power supply | fixed width-variables (height still buggy).
    [IceBoxNew.scad]
2017-12-28 updates the sides to be more 3Dish.
    [0-All.dxf, 1-Holes.dxf, 2-C.dxf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]
